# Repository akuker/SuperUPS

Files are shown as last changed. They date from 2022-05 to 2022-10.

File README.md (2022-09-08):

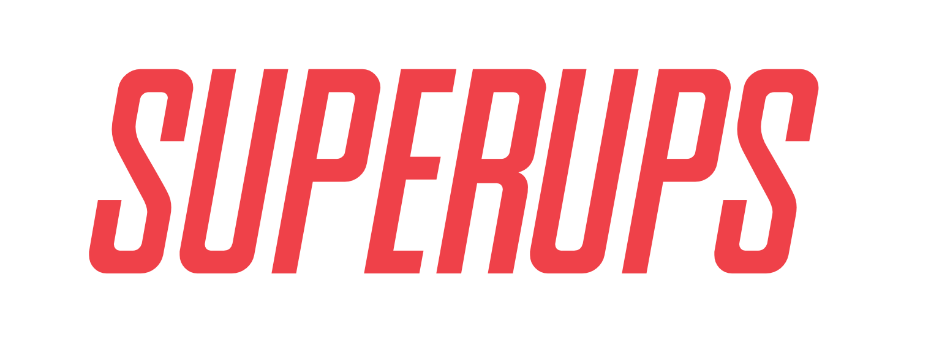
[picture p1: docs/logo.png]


# Supercapacitor UPS board for Raspberry Pi

This is a fork of the original Supercapacitor UPS board for a Raspberry Pi by Scott Baker, http://www.smbaker.com/

This fork is intended to improve producability, documentation and provide tighter integration with the RaSCSI project. This project does NOT require a RaSCSI to function.

See [SETUP.md](SETUP.md) for setup instructions

## Very early 3D renderings

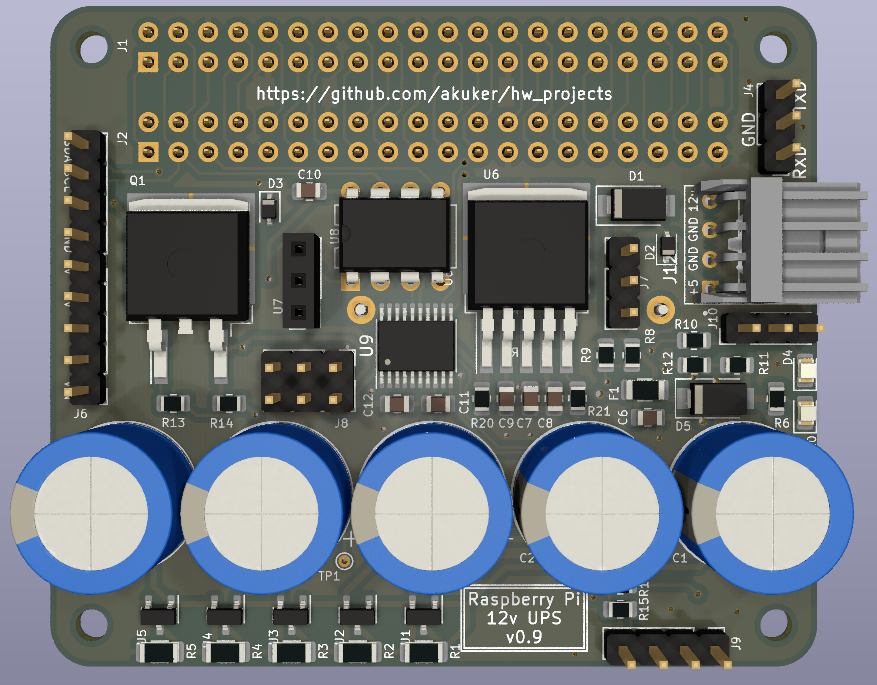
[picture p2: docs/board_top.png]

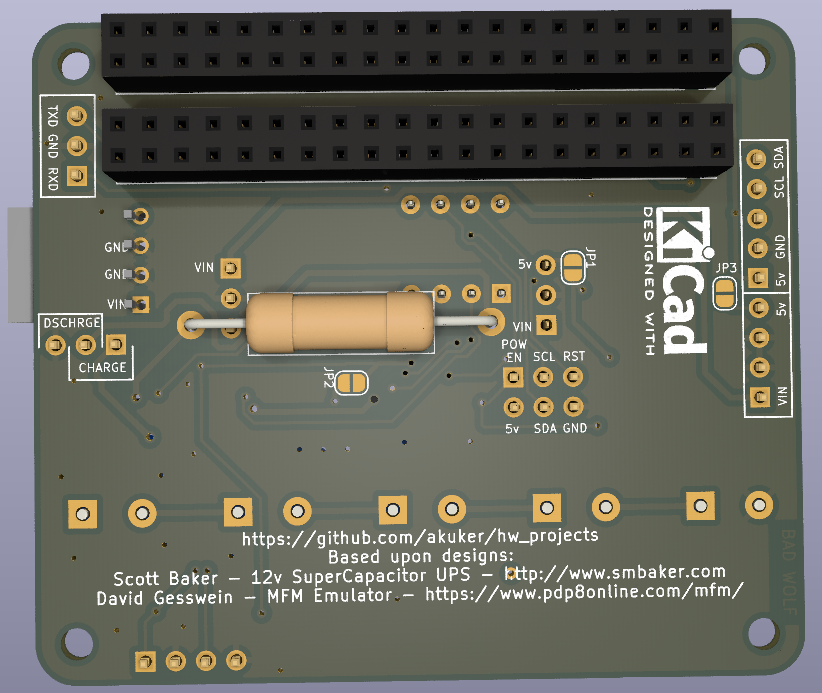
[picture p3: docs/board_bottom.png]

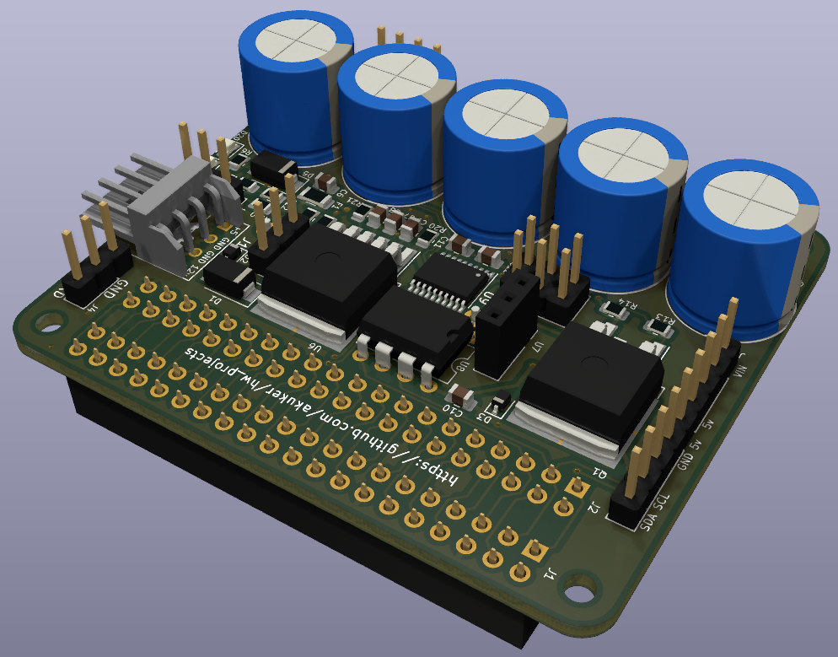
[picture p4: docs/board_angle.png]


## Why not other Supercapacitor designs?

Most of the existing Raspberry Pi UPS designs rely on GPIO pins to alert the Raspberry Pi of a power loss. The RaSCSI design makes heavy usage of the GPIO pins, so there are not sufficient spare to allow this. This design will utilize a microcontroller to manage the power and allow the Rapsberry Pi to read the status through I2C.

# Purpose

These boards are supercapacitor-based uninterruptable power supplies. The supercapacitor charges when power is applied, then when the power supply is terminated, the supercapacitor will operate the device long enough for it to shut down safely.

# Design - 12V board (5v output)

The 12V board uses five 2.7V supercapacitors in series, with 2.7V shunt regulators to ensure that no single capacitor is charged to more than 2.5 volts. A 3W resistor is used to limit the current that charges the capacitors. A jumper is provided to allow the capacitors to be rapid discharged. A mosfet is added to allow the load to be turned on/off.

Note: Scott Baker's original design also included a version of the UPS board that took a 5v input. This fork is focusing on the 12v version and will not include the 5v input version.

# Microcontroller manager

~~An ATTiny85 is used as the controller for the UPS.~~ *Now a STM8 due to the parts shortages.* The microcontroller monitors the battery voltage and the incoming voltage, and switches the load on and off. The microcontroller supports I2C and can be interfaced directly to a raspberry pi.

The microcontroller is also responsible for noticing when power has been restored, and turning the load back on.

[Design Overview](docs/microcontroller_design.md)

# Linux Daemon

A Linux daemon, running on the raspberry pi, monitors the voltage by making i2c queries to the ups board's microcontroller. If the daemon sees the incoming voltage drop, then it will initiate shutdown, by running the `shutdown` command. The shutdown command will terminate processes, unmount the filesystem, etc. 

~~As a final step during shutdown, Linux systemd will execute a script that will tell the microcontroller to turn off the load. At this point, the root filesystem has been remounted readonly, so the board can safely be powered off. ~~

# ~~smb-pi-lib~~

~~Scott Baker has a second repository that has common code for a number of my projects, including the ups. It's located at [https://github.com/sbelectronics/smb-pi-lib](https://github.com/sbelectronics/smb-pi-lib)~~

# Acknowledgements

* Scott Baker for doing a fantastic supercapcitor based UPS design.
* David Gesswein's MFM Emulator was the inspiration for the supercapacitor charing circuit.

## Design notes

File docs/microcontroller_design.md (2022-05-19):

# I2C Register Definitions

| Offset | Description |
| --- | --- |
| 0x00 | Reserved |
| 0x01 | Reserved |
| 0x02 | vin - low (reserved)  |
| 0x03 | vin - high |
| 0x04 | vups - low (reserved) |
| 0x05 | vups - high |
| 0x06 | mosfet switch state |
| 0x07 | on threshold |
| 0x08 | off threshold |
| 0x09 | countdown in 100ms units |
| 0x0A | cycle delay |
| 0x0B | fail-shutdown delay |
| 0x0C | run counter |
| 0x0D | powerup threshold |
| 0x0E | software shutdown threshold |
| 0x0F | R1 resistor value |
| 0x10 | R2 resistor value |
  
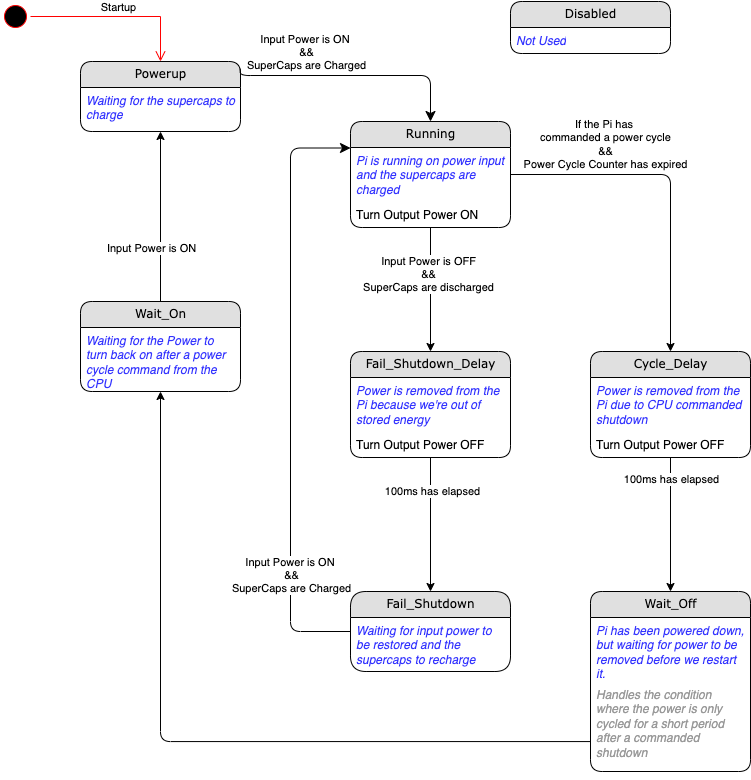
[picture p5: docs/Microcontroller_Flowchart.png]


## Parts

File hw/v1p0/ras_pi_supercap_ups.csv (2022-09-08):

Comment | Designator | Footprint | LCSC
10F | C1,C2,C3,C4,C5 | Capacitor_THT:CP_Radial_D10.0mm_P5.00mm | DNP
1u | C11,C12 | Capacitor_SMD:C_0805_2012Metric | C28323
4.7u | C15,C16 | Capacitor_SMD:C_0805_2012Metric | C1779
4.7n | C17,C20 | Capacitor_SMD:C_0805_2012Metric | C1744
10n | C19 | Capacitor_SMD:C_0805_2012Metric | C1710
33u | C21,C23 | Capacitor_SMD:C_0805_2012Metric | C432920
39p | C22 | Capacitor_SMD:C_0805_2012Metric | C296098
10u | C7,C8,C10,C13 | Capacitor_SMD:C_0805_2012Metric | C15850
100n | C9,C14,C18 | Capacitor_SMD:C_0805_2012Metric | C28233
PTVSHC3D15VUH | D1,D7 | Diode_SMD:D_SOD-323 | C312234
SS54 | D2,D4,D8 | Diode_SMD:D_SMA | C22452
Green | D3,D5,D6,D9 | LED_SMD:LED_0805_2012Metric | C2297
Fuse_Small | F1,F2 | Fuse:Fuse_1206_3216Metric | C140470
MountingHole | H1,H2,H3,H4 | MountingHole:MountingHole_2.7mm_M2.5 | DNP
Conn_01x03 | J1,J3 | Connector_PinHeader_2.54mm:PinHeader_1x03_P2.54mm_Vertical | DNP
Barrel_Jack | J10 | Connector_BarrelJack:BarrelJack_Wuerth_6941xx301002 | C521451
Conn_01x05 | J2 | Connector_PinHeader_2.54mm:PinHeader_1x05_P2.54mm_Vertical | DNP
171826-4 | J5 | TE_171826-4 | DNP
LEDs and Buttons | J6 | Connector_PinHeader_2.54mm:PinHeader_1x04_P2.54mm_Vertical | DNP
STLinkV2 Connector | J7 | Connector_PinHeader_2.54mm:PinHeader_1x04_P2.54mm_Vertical
Raspberry_Pi_2_3 | J8 | Connector_PinSocket_2.54mm:PinSocket_2x20_P2.54mm_Vertical | DNP
Charge Enb | JP1 | Jumper:SolderJumper-2_P1.3mm_Bridged_RoundedPad1.0x1.5mm
6.8uH | L1 | raspberrypi_supercap_ups_lib:Sunltech_SLO0530H | C325965
10 3W | R1,R28 | raspberrypi_supercap_ups_lib:SMT_Resistor_4122 | C306270
2.2k | R10,R11,R13 | Resistor_SMD:R_0805_2012Metric | C17520
0 | R16,R24 | Resistor_SMD:R_0805_2012Metric | C17477
1k | R2,R3,R4,R5,R6 | Resistor_SMD:R_1206_3216Metric | C4410
332k | R21 | Resistor_SMD:R_0805_2012Metric | C17631
68.1k | R22 | Resistor_SMD:R_0805_2012Metric | C17795
49.9k | R23 | Resistor_SMD:R_0805_2012Metric | C17719
10.2k | R25 | Resistor_SMD:R_0805_2012Metric | C17402
1.5k | R26 | Resistor_SMD:R_0805_2012Metric | C4310
200 | R33 | Resistor_SMD:R_0805_2012Metric | C17557
1k | R7,R14,R15,R18,R19,R27 | Resistor_SMD:R_0805_2012Metric | C17513
10k | R8,R9,R12,R20 | Resistor_SMD:R_0805_2012Metric | C17414
Reset | SW1 | SW_TS-1187A-B-A-B | C318884
KA431SMFTF | U1,U2,U3,U4,U5 | Package_TO_SOT_SMD:SOT-23 | C232815
AMS1117-3.3 | U6 | Package_TO_SOT_SMD:SOT-223-3_TabPin2 | C6186
STM8S003F3P | U7 | Package_SO:TSSOP-20_4.4x6.5mm_P0.65mm | C52717
TPS54331DR | U8 | raspberrypi_supercap_ups_lib:SOIC127P599X175-8N | C9865
Logo_Open_Hardware_Small | Z2 | Symbol:CE-Logo_8.5x6mm_SilkScreen
Logo_Open_Hardware_Small | Z4 | Symbol:OSHW-Logo_7.5x8mm_SilkScreen

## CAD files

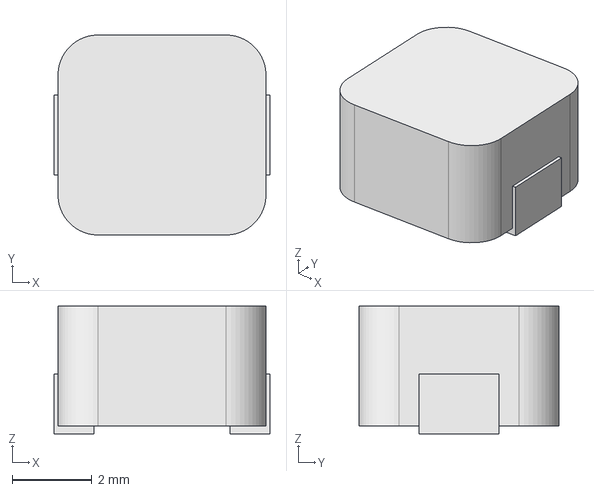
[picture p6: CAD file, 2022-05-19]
hw/v1p0/SLO0530H_Model.FCStd
5.40 x 5.00 x 3.20 mm

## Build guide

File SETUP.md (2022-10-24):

# How to setup SuperUPS

The following assumes you're starting with the base RaSCSI release image from https://github.com/akuker/RaSCSI

## Enable I2C
```
sudo raspi-config
```
Navigate to Interfaces Options -> I2C
When asked if you want I2C to be enabled, select "Yes"

## Install i2c-tools
```
sudo apt install i2c-tools -y
```

## Check if the SuperUPS board is working
```
pi@rascsi:~ $ sudo i2cdetect -y 1
     0  1  2  3  4  5  6  7  8  9  a  b  c  d  e  f
00:                         -- -- -- -- -- -- -- -- 
10: -- -- -- -- -- -- -- -- -- -- -- -- -- -- -- -- 
20: -- -- -- -- -- -- -- -- -- -- -- -- -- -- -- -- 
30: -- -- -- -- -- -- -- -- -- -- -- -- -- -- -- -- 
40: -- -- -- -- -- -- -- -- -- -- -- -- -- -- -- -- 
50: -- -- 52 -- -- -- -- -- -- -- -- -- -- -- -- -- 
60: -- -- -- -- -- -- -- -- -- -- -- -- -- -- -- -- 
70: -- -- -- -- -- -- -- --                         
pi@rascsi:~ $ 
```

The SuperUPS should be at i2c address 0x52

Now, check that you can properly read from it. Registers 16 and 17 are the resistor values of the voltage divider on the board. They should match the example below.
```
pi@rascsi:~ $ i2cget -y 1 0x52 16
0x64
pi@rascsi:~ $ i2cget -y 1 0x52 17
0x16
pi@rascsi:~ $ 
```

## Download the SuperUPS Github repo
```
pi@rascsi:~ $ git clone https://github.com/akuker/SuperUPS.git
```

## Install Python packages
```
sudo pip3 install python-daemon
sudo pip3 install smbus
```

## To manually start the UPS monitor
```
cd ~/SuperUPS/host_monitor/
python3 ./superupsdaemon.py
```

## To dump all of the registers from the UPS controller
```
python3 ups.py
```

## To setup the UPS monitor to run automatically
```
sudo cp SuperUPS/host_monitor/*.py /usr/local/bin/
sudo cp SuperUPS/host_monitor/superups.service /etc/systemd/system/
sudo systemctl daemon-reload
sudo systemctl enable superups.service
sudo systemctl start superups
```

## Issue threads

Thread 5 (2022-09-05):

The wiringpi utility is depreciated in Raspbian 11

stinkerton18, 2022-09-05:
Raspberry Pi Version: 3B
RaSCSI Board: Fullspec, v2.3
SuperUPS Version: 1.0 pre-release

OS Release:
```
console@centris-pi:~ $ lsb_release -a
No LSB modules are available.
Distributor ID: Raspbian
Description:    Raspbian GNU/Linux 11 (bullseye)
Release:        11
Codename:       bullseye
```

Following the install instructions, the first step/prerequisite package install fails on Raspbian 11: Bullseye with the following errors:
```console@centris-pi:~ $ sudo apt-get install -y wiringpi python-smbus python-pip python3-setuptools
Reading package lists... Done
Building dependency tree... Done
Reading state information... Done
Package python-smbus is not available, but is referred to by another package.
This may mean that the package is missing, has been obsoleted, or
is only available from another source

Package python-pip is not available, but is referred to by another package.
This may mean that the package is missing, has been obsoleted, or
is only available from another source
However the following packages replace it:
  python3-pip

Package wiringpi is not available, but is referred to by another package.
This may mean that the package is missing, has been obsoleted, or
is only available from another source

E: Package 'wiringpi' has no installation candidate
E: Package 'python-smbus' has no installation candidate
E: Package 'python-pip' has no installation candidate
```

stinkerton18, 2022-09-05:
In searching, I found this article: https://raspberrypi.stackexchange.com/questions/133251/wiringpi-is-missing-from-bullseye-how-do-i-install-it
According to the article, pigpio is the better option anyways and I see the setup instructions for it in the SETUP doc, This might just be a doc clean up bug.

akuker, 2022-09-07:
Could you take a look at pull request https://github.com/akuker/SuperUPS/pull/8 ? I think this addresses your concern.

The new version shouldn't use wiring pi.

stinkerton18, 2022-09-07:
Can confirm, pull request #8 removed the wiring pi and pigpiod needs

Closed 2022-09-07.

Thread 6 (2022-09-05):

Host Monitoring Script missing dependency libraries

stinkerton18, 2022-09-05:
Raspberry Pi Version: 3B
RaSCSI Board: Fullspec, v2.3
SuperUPS Version: 1.0 pre-release

OS Release:
```
console@centris-pi:~ $ lsb_release -a
No LSB modules are available.
Distributor ID: Raspbian
Description:    Raspbian GNU/Linux 11 (bullseye)
Release:        11
Codename:       bullseye
```

When setting up the host_monitior script, upscontrol.py, it is attempting to import libraries that are missing from this repository but are included in a separate repository from the original/forked project. These missing dependencies are as follows:
- https://github.com/sbelectronics/smb-pi-lib/blob/master/smbpi/ups.py
- https://github.com/sbelectronics/smb-pi-lib/blob/master/smbpi/i2c_with_crc.py

stinkerton18, 2022-09-05:
I've combined these two into a single python script (kept getting errors with the i2c_with_crc module failing to import even with an absolute path added).
This is the contents of ups.py:
```
from __future__ import print_function
import crc8
import time
import traceback

class I2CError(Exception):
    pass

class ReceiveCRCError(Exception):
    pass

class ReceiveSizeError(Exception):
    pass

class ReceiveUninitializedError(Exception):
    pass

class CRCError(Exception):
    pass

class NoMoreRetriesError(Exception):
    pass

class I2CWithCrc:
    def __init__(self, bus=None, addr=0x4, pi=None, sdaPin=2, sclPin=3):
        self.bus = bus
        self.addr = addr
        self.pi = pi
        self.sdaPin = sdaPin
        self.sclPin = sclPin

        self.errorIO = 0
        self.errorCRC = 0
        self.errorReceiveCRC = 0
        self.errorReceiveUninitialized = 0
        self.errorReceiveSize = 0
        self.errorSuccess = 0

        if (self.pi):
            try:
                self.pi.bb_i2c_close(self.sdaPin)
            except:
                pass
            # pigpiod
            self.pi.bb_i2c_open(self.sdaPin, self.sclPin, 100000)

    @property
    def errorCount(self):
        return self.errorIO + self.errorReceiveCRC + self.errorReceiveUninitialized + self.errorReceiveSize + self.errorCRC

    def readreg_once(self, reg):
        if self.bus:
            hash = crc8.crc8()
            hash.update(chr(reg))
            crc = hash.digest()
            self.bus.write_i2c_block_data(self.addr, reg, [ord(crc)])

            data = self.bus.read_byte(self.addr)
            crc = self.bus.read_byte(self.addr)
        else:
            hash = crc8.crc8()
            hash.update(chr(reg))
            crc = hash.digest()
            (count, i2cdata) = self.pi.bb_i2c_zip(self.sdaPin,
                (4, self.addr,      # set addr to self.addr
                2, 7, 2, reg, crc,  # start, write two byte (reg, crc)
                2, 6, 1,            # (re)start, read one byte
                2, 6, 1,            # (re)start, read one byte
                3,                  # stop
                0))                 # end
            if count<0:
                raise I2CError("i2c error")
            if count!=2:
                raise I2CError("i2c wrong byte count")

            data = i2cdata[0]
            crc = i2cdata[1]

        if (data == 0xFF) and (crc == 0xFF):
            raise ReceiveCRCError("receive crc error")
        if (data == 0xFF) and (crc == 0xFE):
            raise ReceiveSizeError("receive size error")
        if (data == 0xFF) and (crc == 0xFD):
            raise ReceiveUninitializedError("receive uninitialized error")

        hash = crc8.crc8()
        hash.update(chr(data))
        if crc != ord(hash.digest()):
            raise CRCError("crc error, data=%2X, crc=%2X, localCrc=%X" % (data, crc, ord(hash.digest())))

        return data

    def writereg_once(self, reg, v):
        if self.bus:
            hash = crc8.crc8()
            hash.update(chr(reg))
            hash.update(chr(v))
            crc = hash.digest()
            self.bus.write_i2c_block_data(self.addr, reg, [v, ord(crc)])

            readBack = self.bus.read_byte(self.addr)
            crc = self.bus.read_byte(self.addr)
        else:
            hash = crc8.crc8()
            hash.update(chr(reg))
            hash.update(chr(v))
            crc = hash.digest()
            (count, i2cdata) = self.pi.bb_i2c_zip(self.sdaPin,
                (4, self.addr,         # set addr to self.addr
                2, 7, 3, reg, v, crc,  # start, write three bytes (reg, v, crc)
                2, 6, 1,            # (re)start, read one byte
                2, 6, 1,            # (re)start, read one byte
                3,                  # stop
                0))                 # end
            if count<0:
                raise I2CError("i2c error")
            if count!=2:
                raise I2CError("i2c wrong byte count")

            readBack = i2cdata[0]
            crc = i2cdata[1]

        # note that readBack will actually return the next register. But,
        # that's alright, we don't care -- we just want to check to make
        # sure we didn't get an error back.

        if (readBack == 0xFF) and (crc == 0xFF):
            raise ReceiveCRCError("receive crc error")
        if (readBack == 0xFF) and (crc == 0xFE):
            raise ReceiveSizeError("receive size error")
        if (readBack == 0xFF) and (crc == 0xFD):
            raise ReceiveUninitializedError("receive uninitialized error")

        hash = crc8.crc8()
        hash.update(chr(readBack))
        if crc != ord(hash.digest()):
            raise CRCError("crc error, readBack=%2X, crc=%2X, localCrc=%X" % (readBack, crc, ord(hash.digest())))

    def readreg(self, reg):
        for i in range(0, 10):
            try:
                v = self.readreg_once(reg)
                self.errorSuccess += 1
                return v
            except I2CError:
                self.errorIO += 1
            except IOError:
                self.errorIO += 1
            except ReceiveCRCError:
                self.errorReceiveCRC += 1
            except ReceiveSizeError:
                self.errorReceiveSize += 1
            except ReceiveUninitializedError:
                self.errorReceivedUninitialized += 1
            except CRCError:
                self.errorCRC += 1
        raise NoMoreRetriesError()

    def writereg(self, reg, v):
        for i in range(0, 10):
            try:
                self.writereg_once(reg, v)
                self.errorSuccess += 1
                return
            except I2CError:
                self.errorIO += 1
            except IOError:
                self.errorIO += 1
            except ReceiveCRCError:
                self.errorReceiveCRC += 1
            except ReceiveSizeError:
                self.errorReceiveSize += 1
            except ReceiveUninitializedError:
                self.errorReceivedUninitialized += 1
            except CRCError:
                self.errorCRC += 1
            except TypeError:
                pass
        raise NoMoreRetriesError()

    # different capitalization
    def readReg(self, reg):
        return self.readreg(reg)

    # different capitalization
    def writeReg(self, reg, v):
        self.writereg(reg, v)

class UPS(I2CWithCrc):
    def __init__(self, bus=None, addr=0x4, pi=None, sdaPin=2, sclPin=3):
        I2CWithCrc.__init__(self, bus, addr, pi, sdaPin, sclPin)

        try:
            self.r1 = self.readR1()
            self.r2 = self.readR2()
            print("XXX", self.r1, self.r2)
        except:
            print("WARNING: Failed to read R1 and R2")
            traceback.print_exc()

        self.states = {0: "DISABLED",
                       1: "WAIT_OFF",
                       2: "WAIT_ON",
                       3: "POWERUP",
                       4: "RUNNING",
                       5: "FAIL_SHUTDOWN",
                       6: "FAIL_SHUTDOWN_DELAY",
                       7: "CYCLE_DELAY"}

    def vConv(self, x):
        return float(x)*2.56*(self.r1+self.r2)/self.r2/256.0

    def setCountdown(self, ms):
        if (ms is not None) and (ms>0) and (ms<100):
            # the minimum is 100ms
            ms=100
        return self.writereg(9, ms/100)

    def readR1(self):
        return self.readreg(16)

    def readR2(self):
        return self.readreg(17)

    def readCountdown(self):
        return self.readreg(9)

    def readVIN(self):
        return self.vConv(self.readreg(3))

    def readVUPS(self):
        return self.vConv(self.readreg(5))

    def readOnThresh(self):
        return self.vConv(self.readreg(7))

    def readOffThresh(self):
        return self.vConv(self.readreg(8))

    def readPowerUpThresh(self):
        return self.vConv(self.readreg(14))

    def readShutdownThresh(self):
        return self.vConv(self.readreg(15))

    def readMosfet(self):
        return self.readreg(6)

    def setMosfet(self, v):
        self.writeReg(6, v)

    def readState(self):
        return self.readreg(10)

    def readRunCounter(self):
        return self.readreg(13)

    def readStateStr(self):
        state = self.readState()
        return self.states.get(state, str(state))

    def testWrite(self, x):
        self.writereg(0, x)

def diags(ups):
    print(ups.readreg(0), ups.readreg(2), ups.readreg(4), ups.readreg(6), ups.readreg(7), ups.readreg(8))
    print("onThresh=%0.2f, offThresh=%0.2f" % (ups.readOnThresh(), ups.readOffThresh()))

    lastVUPS = None
    lastVIN = None
    lastState = None
    lastCountdown = None
    lastErrorCount = 0
    count = 0
    while True:
        try:
            VUPS = ups.readVUPS()
            VIN = ups.readVIN()
            state = ups.readStateStr()
            runCounter = ups.readRunCounter()
            countdown = ups.readCountdown()
        except NoMoreRetriesError:
            continue

        try:
            ups.testWrite(count % 256)
        except NoMoreRetriesError:
            pass

        if (VUPS != lastVUPS) or (VIN != lastVIN) or (state != lastState) or (countdown != lastCountdown):
            print("%-20s, vin=%0.2f, vups=%0.2f rc=%d cd=%d" % (state, VIN, VUPS, runCounter, countdown))
            lastVUPS = VUPS
            lastVIN = VIN
            state = lastState

        errorCount = ups.errorCount
        if errorCount != lastErrorCount:
            print("ERR: success=%d, io=%d, crc=%d, rcv_crc=%d, rcv_size=%d, rcv_uninit=%d" % (ups.errorSuccess, ups.errorIO, ups.errorCRC, ups.errorReceiveCRC, ups.errorReceiveSize, ups.errorReceiveUninitialized))
            lastErrorCount = errorCount

        time.sleep(0.01)

def main():
    #import smbus
    #bus = smbus.SMBus(1)
    #ups = UPS(bus=bus)

    import pigpio
    pi = pigpio.pi()
    ups = UPS(pi=pi)

    diags(ups)

if __name__ == "__main__":
    main()
```

Then line 11 of upscontrol.py should be changed to:
`from ups import UPS, diags`

_if_ the ups.py script is placed in the same directory as the upscontrol.py script of course.

akuker, 2022-09-07:
Could you take a look at pull request https://github.com/akuker/SuperUPS/pull/8 ? I think this addresses your concern.

Note: I've SUBSTANTIALLY simplified the python script from Dr. Baker's original version. There was a lot of functionality that I don't think is needed right away.

stinkerton18, 2022-09-07:
100% can confirm with pull request #8.

Closed 2022-09-07.

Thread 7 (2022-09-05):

upscontrol.py script is not Python3 compliant

stinkerton18, 2022-09-05:
Raspberry Pi Version: 3B
RaSCSI Board: Fullspec, v2.3
SuperUPS Version: 1.0 pre-release

OS Release:
```
console@centris-pi:~ $ lsb_release -a
No LSB modules are available.
Distributor ID: Raspbian
Description:    Raspbian GNU/Linux 11 (bullseye)
Release:        11
Codename:       bullseye
```

The upscontrol.py script is using the older Python2-based print statements. I have corrected this for Python3 and can create a merge request with the updated (or renamed for python3) upscontrol.py script.

akuker, 2022-09-07:
I've made significant updates to the python code that is on a branch. I haven't merged it to main yet :-(

https://github.com/akuker/SuperUPS/blob/host_controller/host_monitor/upscontrol.py

akuker, 2022-09-07:
Could you take a look at pull request #8 ? I think this addresses your concern.

stinkerton18, 2022-09-07:
Yes indeed. Since there's a different script, I don't see a reason to publish the minor changes to make it python3 compliant in this repo.

Closed 2022-09-07.

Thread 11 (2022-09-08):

Version 1.0 hardware is missing pull-up resistors for the I2C bus

akuker, 2022-09-08:
The board should be modified to add pull-up resistors for the i2c bus. Current 1.0 boards have modifications to work around this.

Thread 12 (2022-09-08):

Re-do board layout to fit within the Raspberry Pi footprint

akuker, 2022-09-08:
Right now, the super caps extend beyond the footprint of the raspberry pi. Ideally, they should be within that footprint.

Some space saving ideas:
- Several of the headers can be removed, as they were only for debugging
- The reset switch could be moved to the bottom and depopulated for most board. This is only used for firmware development (if even then)
- The voltage sensing resistors could be dropped down to 0402, since they have almost no current flowing through them.

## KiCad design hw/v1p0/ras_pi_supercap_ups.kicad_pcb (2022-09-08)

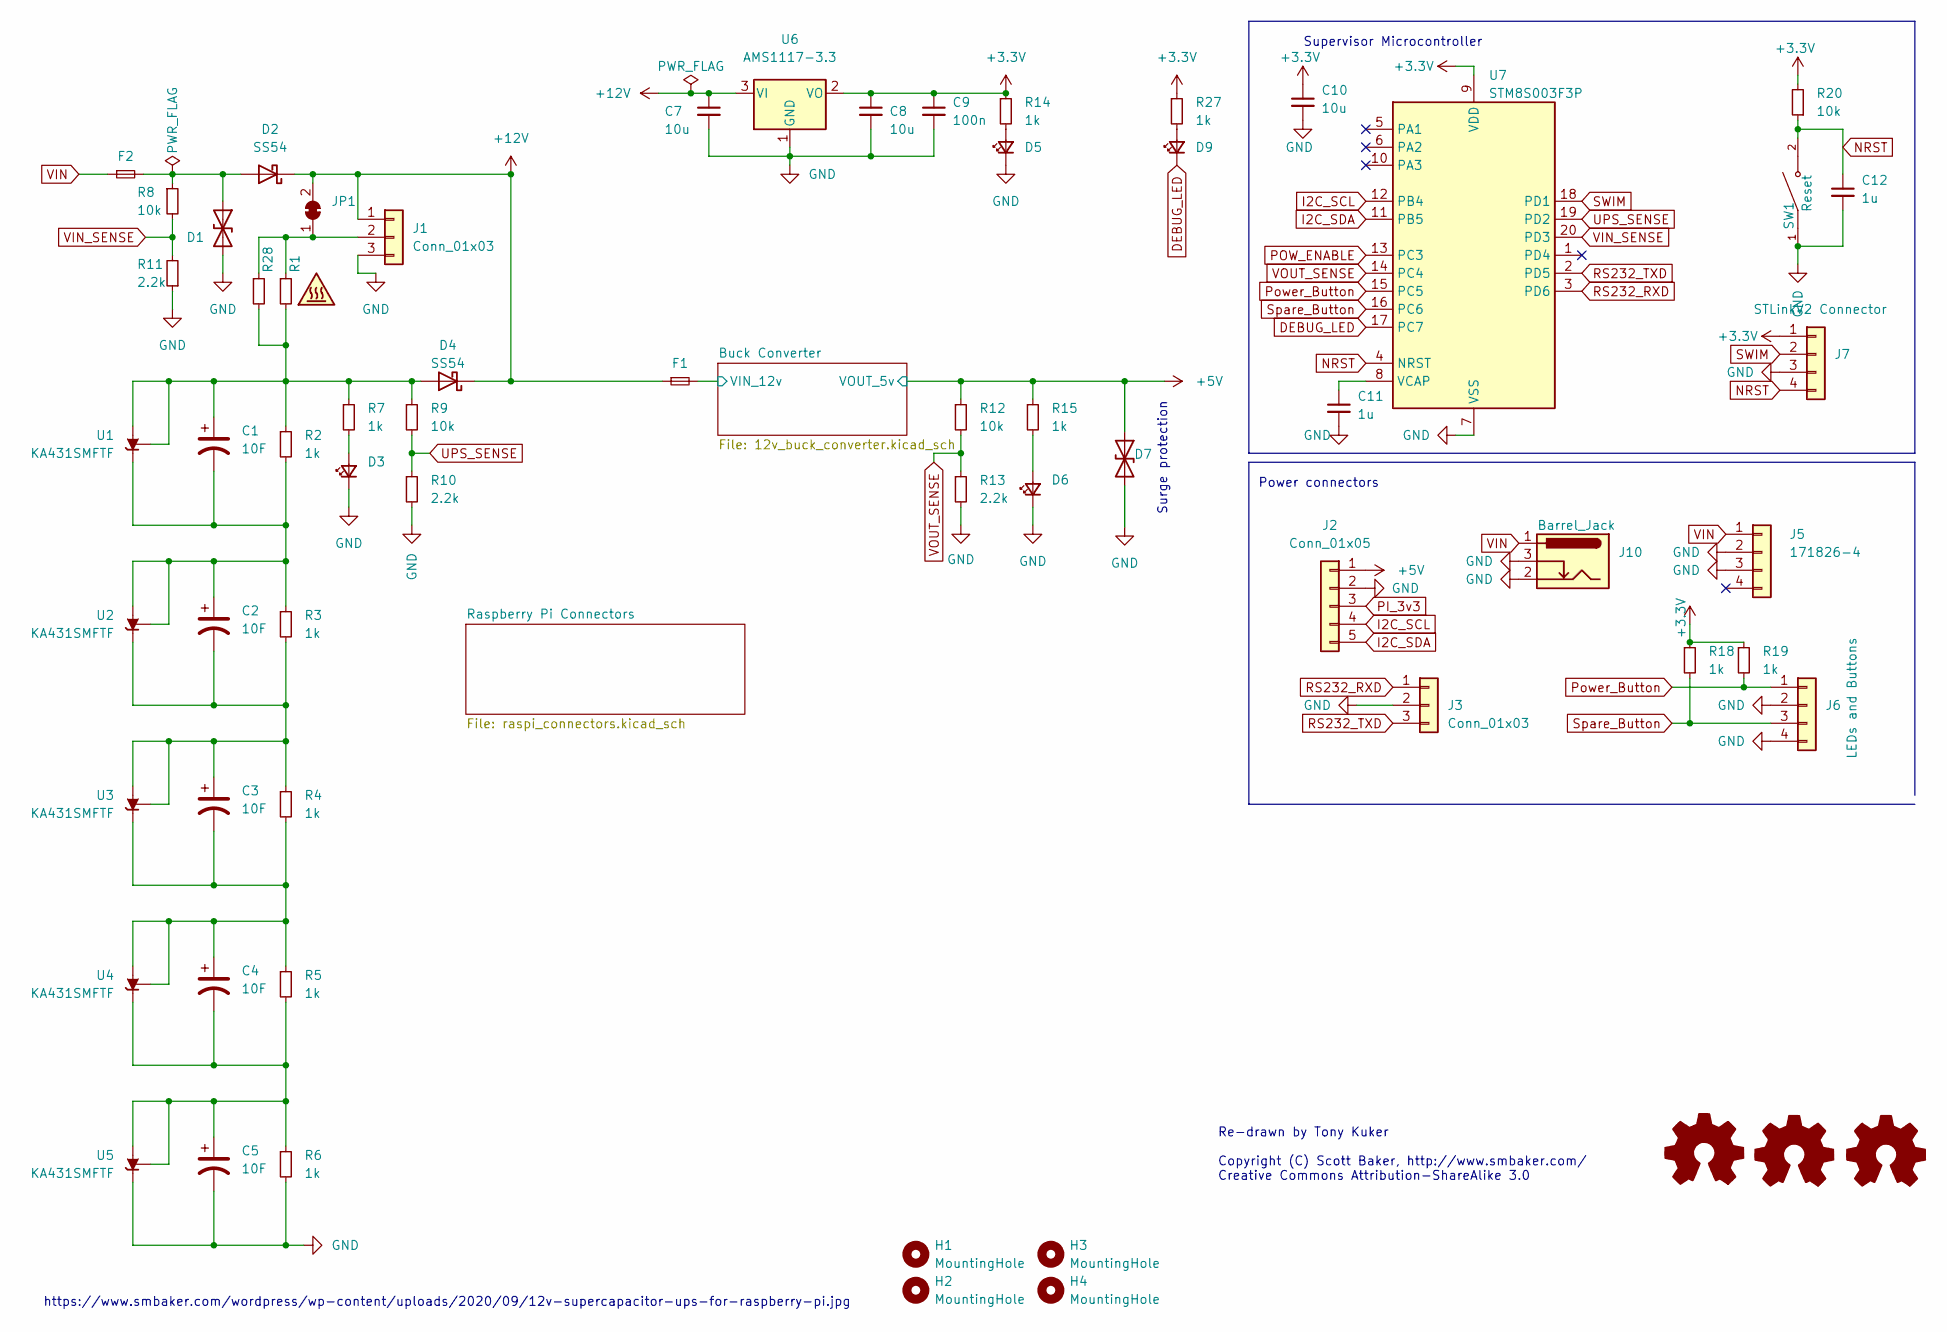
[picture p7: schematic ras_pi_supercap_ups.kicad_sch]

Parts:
C1, C2, C3, C4, C5: 10F; CP_Radial_D10.0mm_P5.00mm; DigikeyPN 478-10996-ND
C7, C8, C10: 10u; C_0805_2012Metric; DigikeyPN 445-FK26X7R1E106K-ND
C9: 100n; C_0805_2012Metric; LCSC C28233
C11, C12: 1u; C_0805_2012Metric; LCSC C28323
D1, D7: PTVSHC3D15VUH; D_SOD-323; LCSC C312234
D2, D4: SS54; D_SMA; LCSC C22452
D3, D5, D6, D9: Green; LED_0805_2012Metric; LCSC C2297
F1, F2: Fuse_Small; Fuse_1206_3216Metric; LCSC C140470
H1, H2, H3, H4: MountingHole; MountingHole_2.7mm_M2.5; LCSC DNP
J1: Conn_01x03; PinHeader_1x03_P2.54mm_Vertical; DigikeyPN NA
J2: Conn_01x05; PinHeader_1x05_P2.54mm_Vertical; DigikeyPN NA
J3: Conn_01x03; PinHeader_1x03_P2.54mm_Vertical; DigikeyPN A106204-ND
J5: 171826-4; TE_171826-4; LCSC DNP
J6: LEDs and Buttons; PinHeader_1x04_P2.54mm_Vertical; LCSC DNP
J7: STLinkV2 Connector; PinHeader_1x04_P2.54mm_Vertical
J10: Barrel_Jack; BarrelJack_Wuerth_6941xx301002; LCSC C521451
JP1: Charge Enb; SolderJumper-2_P1.3mm_Bridged_RoundedPad1.0x1.5mm
R1, R28: 10 3W; SMT_Resistor_4122; DigikeyPN YAG1228CT-ND
R2, R3, R4, R5, R6: 1k; R_1206_3216Metric; DigikeyPN CF14JT1K00CT-ND
R7, R14, R15, R18, R19, R27: 1k; R_0805_2012Metric; DigikeyPN CF14JT1K00CT-ND
R8, R9, R12, R20: 10k; R_0805_2012Metric; DigikeyPN CF14JT10K0CT-ND
R10, R11, R13: 2.2k; R_0805_2012Metric; DigikeyPN CF14JT2K20TR-ND
SW1: Reset; SW_TS-1187A-B-A-B; PARTREV A0; LCSC C318884
U1, U2, U3, U4, U5: KA431SMFTF; SOT-23; LCSC C232815
U6: AMS1117-3.3; SOT-223-3_TabPin2; LCSC C6186
U7: STM8S003F3P; TSSOP-20_4.4x6.5mm_P0.65mm; LCSC C52717
Z1: SYM_Hot_Small; hot_warning_4
Z2: Logo_Open_Hardware_Small; CE-Logo_8.5x6mm_SilkScreen
Z3: Logo_Open_Hardware_Small; KiCad-Logo_5mm_Copper
Z4: Logo_Open_Hardware_Small; OSHW-Logo_7.5x8mm_SilkScreen

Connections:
+3V3: C8.1, C9.1, C10.1, J7.1, R14.1, R18.1, R19.1, R20.2, R27.1, U6.2 (VO), U7.9 (VDD)
+5V: D7.1 (A1), J2.1, R12.1, R15.1; also elsewhere on the board
+12V: C7.1, D2.1 (K), D4.1 (K), F1.1, J1.1, JP1.2 (B), U6.3 (VI)
/Buck Converter/VIN_12v: F1.2; also elsewhere on the board
DEBUG_LED: D9.1 (K), U7.17 (PC7)
GND: C5.2, C7.2, C8.2, C9.2, C10.2, C11.2, C12.2, D1.2 (A2), D3.1 (K), D5.1 (K), D6.1 (K), D7.2 (A2), J1.3, J2.2, J3.2, J5.2, J5.3, J6.2, J6.4, J7.3, J10.2, J10.3, R6.2, R10.2, R11.1, R13.2, SW1.1, U5.2 (K), U6.1 (GND), U7.7 (VSS); also elsewhere on the board
NRST: C12.1, J7.4, R20.1, SW1.2, U7.4 (NRST)
unnamed: C1.1, D4.2 (A), R1.2, R2.1, R7.1, R9.1, R28.2, U1.1 (REF), U1.3 (A)
unnamed: C1.2, C2.1, R2.2, R3.1, U1.2 (K), U2.1 (REF), U2.3 (A)
unnamed: C2.2, C3.1, R3.2, R4.1, U2.2 (K), U3.1 (REF), U3.3 (A)
unnamed: C3.2, C4.1, R4.2, R5.1, U3.2 (K), U4.1 (REF), U4.3 (A)
unnamed: C4.2, C5.1, R5.2, R6.1, U4.2 (K), U5.1 (REF), U5.3 (A)
unnamed: C11.1, U7.8 (VCAP)
unnamed: D1.1 (A1), D2.2 (A), F2.2, R8.1
unnamed: D3.2 (A), R7.2
unnamed: D5.2 (A), R14.2
unnamed: D6.2 (A), R15.2
unnamed: D9.2 (A), R27.2
unnamed: J1.2, JP1.1 (A), R1.1, R28.1
PI_3v3: J2.3; also elsewhere on the board
POW_ENABLE: U7.13 (PC3); also elsewhere on the board
Power_Button: J6.1, R19.2, U7.15 (PC5)
RS232_RXD: J3.1, U7.3 (PD6)
RS232_TXD: J3.3, U7.2 (PD5)
SWIM: J7.2, U7.18 (PD1)
Spare_Button: J6.3, R18.2, U7.16 (PC6)
UPS_SENSE: R9.2, R10.1, U7.19 (PD2)
VIN: F2.1, J5.1, J10.1
VIN_SENSE: R8.2, R11.2, U7.20 (PD3)
VOUT_SENSE: R12.2, R13.1, U7.14 (PC4)

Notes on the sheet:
https://www.smbaker.com/wordpress/wp-content/uploads/2020/09/12v-supercapacitor-ups-for-raspberry-pi.jpg
Power connectors
Re-drawn by Tony Kuker Copyright (C) Scott Baker, http://www.smbaker.com/ Creative Commons Attribution-ShareAlike 3.0
Surge protection
Supervisor Microcontroller

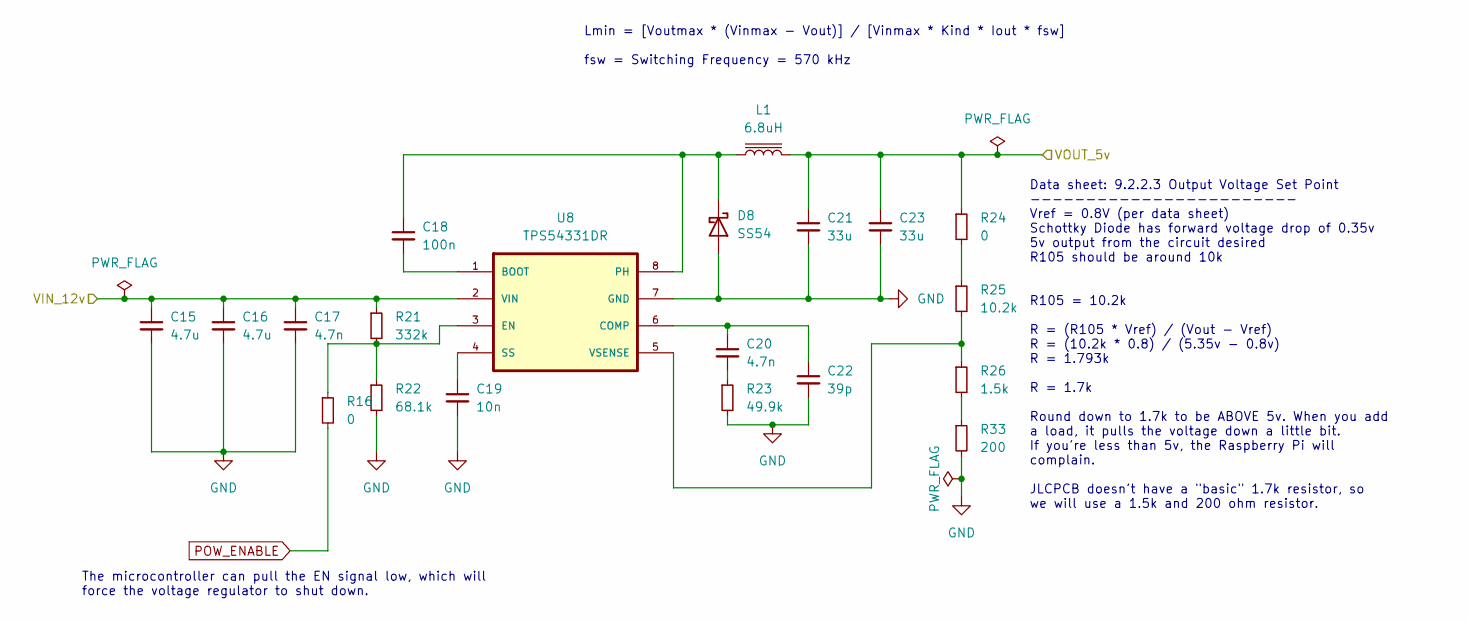
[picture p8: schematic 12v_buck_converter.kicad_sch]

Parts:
C15, C16: 4.7u; C_0805_2012Metric; LCSC C1779
C17, C20: 4.7n; C_0805_2012Metric; LCSC C1744
C18: 100n; C_0805_2012Metric; LCSC C28233
C19: 10n; C_0805_2012Metric; LCSC C1710
C21, C23: 33u; C_0805_2012Metric; LCSC C432920
C22: 39p; C_0805_2012Metric; LCSC C296098
D8: SS54; D_SMA; LCSC C22452
L1: 6.8uH; Sunltech_SLO0530H; LCSC C325965
R16: 0; R_0805_2012Metric; DigikeyPN CF14JT1K00CT-ND
R21: 332k; R_0805_2012Metric; LCSC C17631
R22: 68.1k; R_0805_2012Metric; LCSC C17795
R23: 49.9k; R_0805_2012Metric; LCSC C17719
R24: 0; R_0805_2012Metric; LCSC C17477
R25: 10.2k; R_0805_2012Metric; LCSC C17402
R26: 1.5k; R_0805_2012Metric; LCSC C4310
R33: 200; R_0805_2012Metric; LCSC C17557
U8: TPS54331DR; SOIC127P599X175-8N; LCSC C9865

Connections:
+5V: C21.1, C23.1, L1.2, R24.1; also elsewhere on the board
/Buck Converter/VIN_12v: C15.1, C16.1, C17.1, R21.1, U8.2 (VIN); also elsewhere on the board
GND: C15.2, C16.2, C17.2, C19.2, C21.2, C22.2, C23.2, D8.2 (A), R22.2, R23.2, R33.2, U8.7 (GND); also elsewhere on the board
unnamed: C18.1, D8.1 (K), L1.1, U8.8 (PH)
unnamed: C18.2, U8.1 (BOOT)
unnamed: C19.1, U8.4 (SS)
unnamed: C20.1, C22.1, U8.6 (COMP)
unnamed: C20.2, R23.1
unnamed: R16.1, R21.2, R22.1, U8.3 (EN)
unnamed: R24.2, R25.1
unnamed: R25.2, R26.1, U8.5 (VSENSE)
unnamed: R26.2, R33.1
POW_ENABLE: R16.2; also elsewhere on the board

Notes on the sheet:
The microcontroller can pull the EN signal low, which will force the voltage regulator to shut down.
Data sheet: 9.2.2.3 Output Voltage Set Point ------------------------ Vref = 0.8V (per data sheet) Schottky Diode has forward voltage drop of 0.35v 5v output from the circuit desired R105 should be around 10k R105 = 10.2k R = (R105 * Vref) / (Vout - Vref) R = (10.2k * 0.8) / (5.35v - 0.8v) R = 1.79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
Lmin = [Voutmax * (Vinmax - Vout)] / [Vinmax * Kind * Iout * fsw] fsw = Switching Frequency = 570 kHz

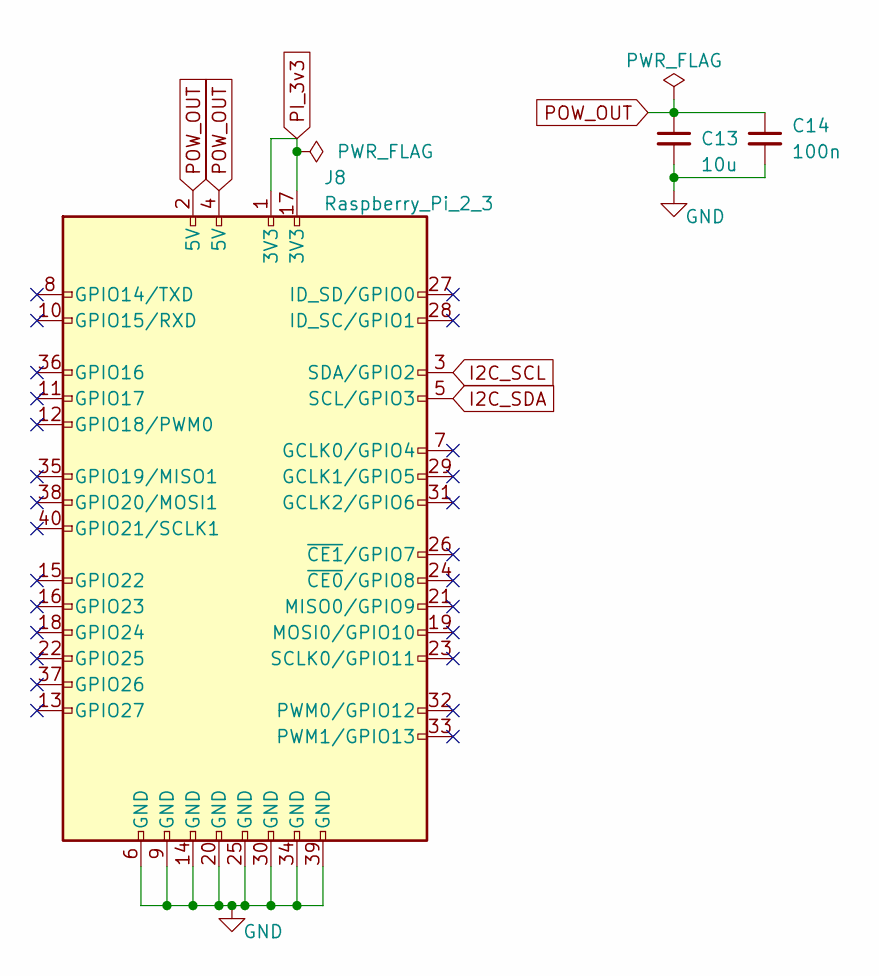
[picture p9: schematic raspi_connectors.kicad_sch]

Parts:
C13: 10u; C_0805_2012Metric; DigikeyPN 445-FK26X7R1E106K-ND
C14: 100n; C_0805_2012Metric; LCSC C28233
J8: Raspberry_Pi_2_3; PinSocket_2x20_P2.54mm_Vertical; LCSC DNP

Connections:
+5V: C13.1, C14.1, J8.2 (5V), J8.4 (5V); also elsewhere on the board
GND: C13.2, C14.2, J8.6 (GND), J8.9 (GND), J8.14 (GND), J8.20 (GND), J8.25 (GND), J8.30 (GND), J8.34 (GND), J8.39 (GND); also elsewhere on the board
PI_3v3: J8.1 (3V3), J8.17 (3V3); also elsewhere on the board

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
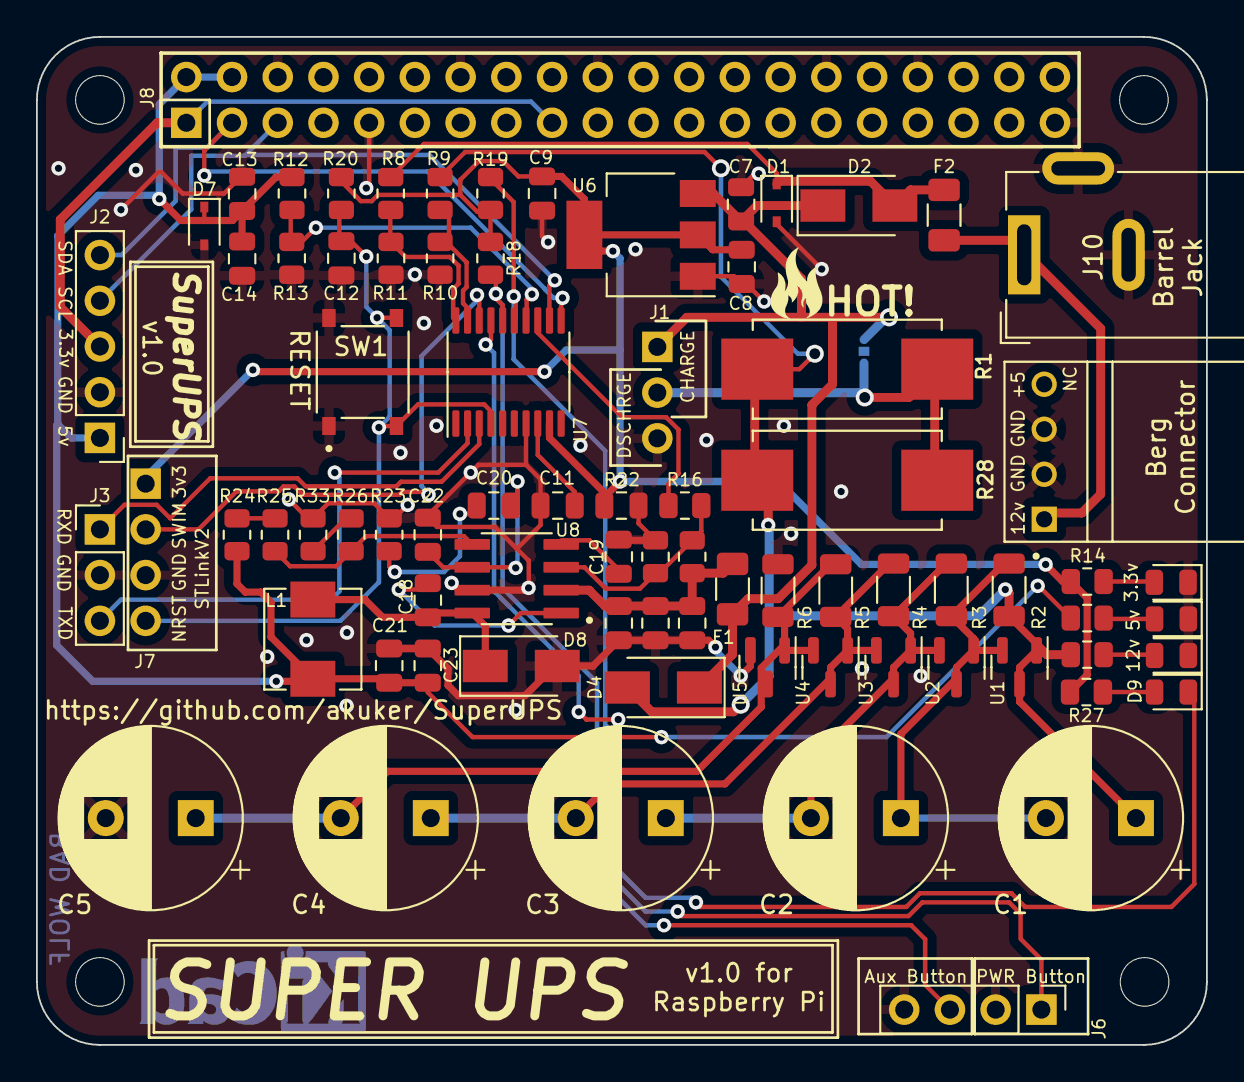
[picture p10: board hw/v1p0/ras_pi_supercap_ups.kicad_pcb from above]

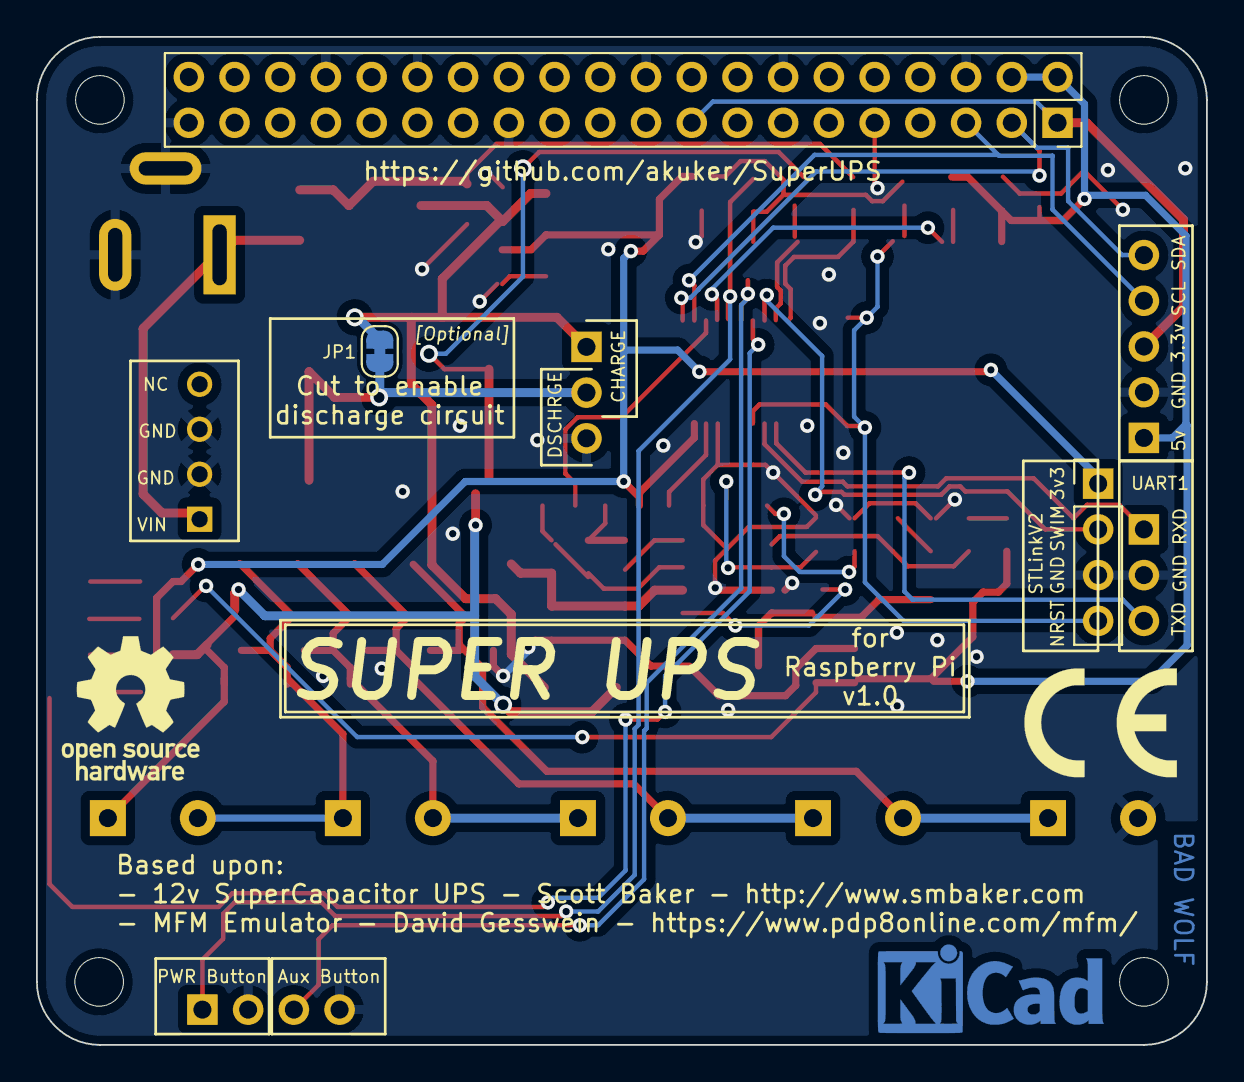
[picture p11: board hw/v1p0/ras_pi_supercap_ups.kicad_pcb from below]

Board: 2 copper layers, 65.0 x 56.0 mm, 88 parts (7 on the bottom side), 41 nets.

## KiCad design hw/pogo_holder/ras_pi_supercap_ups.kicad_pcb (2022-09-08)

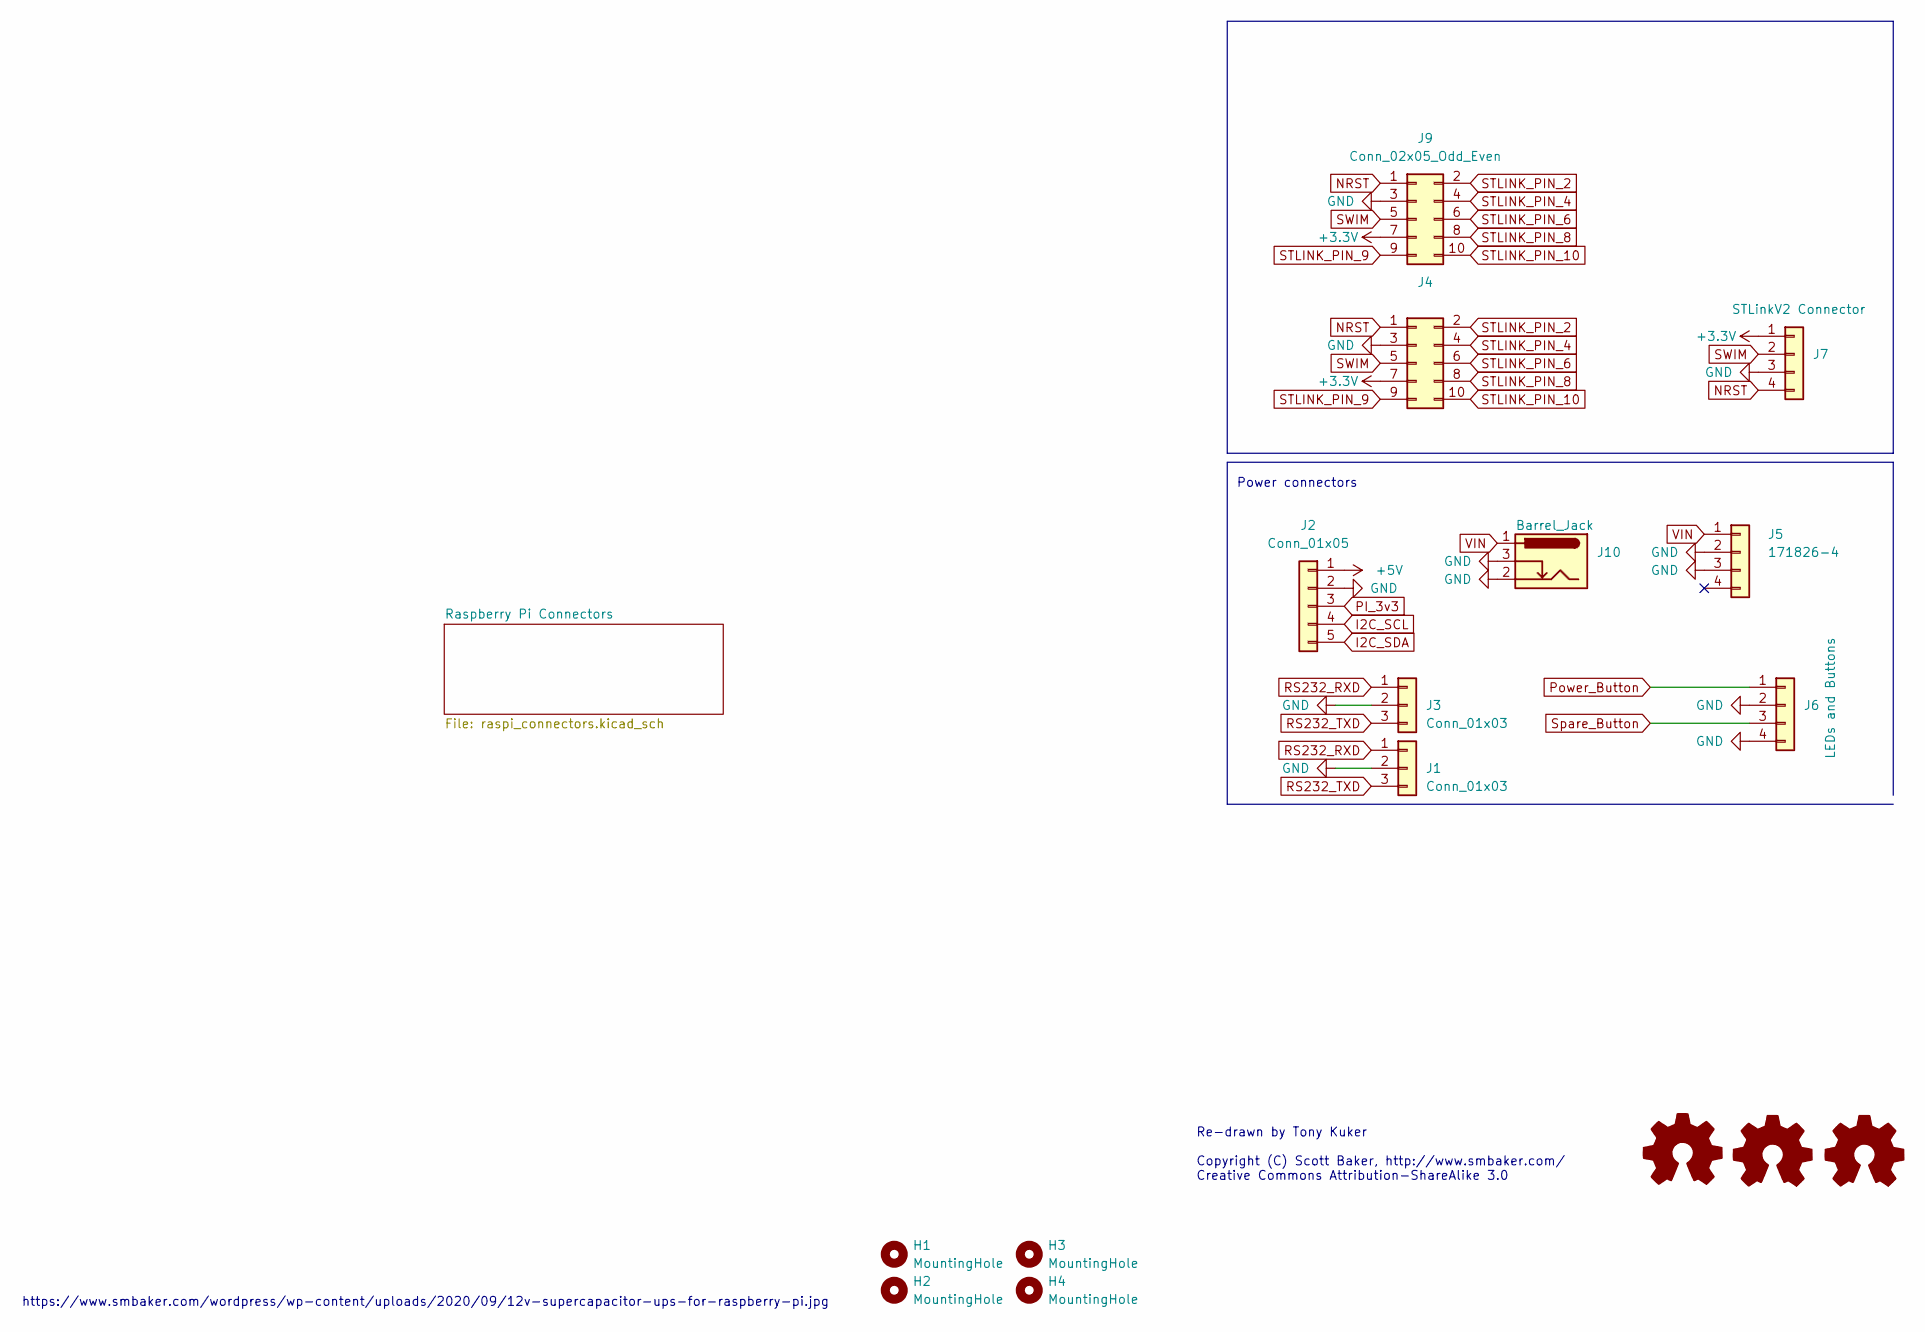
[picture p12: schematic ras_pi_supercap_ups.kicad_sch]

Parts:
H1, H2, H3, H4: MountingHole; MountingHole_2.7mm_M2.5; LCSC DNP
J1, J3: Conn_01x03; PinHeader_1x03_P2.54mm_Vertical; DigikeyPN A106204-ND
J2: Conn_01x05; PinHeader_1x05_P2.54mm_Vertical; DigikeyPN NA
J4: (no value)
J5: 171826-4; TE_171826-4; LCSC DNP
J6: LEDs and Buttons; PinHeader_1x04_P2.54mm_Vertical; LCSC DNP
J7: STLinkV2 Connector; PinHeader_1x04_P2.54mm_Vertical
J9: Conn_02x05_Odd_Even; PinHeader_2x05_P2.54mm_Vertical
J10: Barrel_Jack; BarrelJack_Wuerth_6941xx301002; LCSC C521451
Z2: Logo_Open_Hardware_Small; CE-Logo_8.5x6mm_SilkScreen
Z3: Logo_Open_Hardware_Small; KiCad-Logo_5mm_Copper
Z4: Logo_Open_Hardware_Small; OSHW-Logo_7.5x8mm_SilkScreen

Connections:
+3V3: J4.7, J7.1, J9.7
+5V: J2.1
GND: J1.2, J2.2, J3.2, J4.3, J5.2, J5.3, J6.2, J6.4, J7.3, J9.3, J10.2, J10.3; also elsewhere on the board
I2C_SCL: J2.4; also elsewhere on the board
I2C_SDA: J2.5; also elsewhere on the board
NRST: J4.1, J7.4, J9.1
PI_3v3: J2.3
Power_Button: J6.1
RS232_RXD: J1.1, J3.1
RS232_TXD: J1.3, J3.3
STLINK_PIN_2: J4.2, J9.2
STLINK_PIN_4: J4.4, J9.4
STLINK_PIN_6: J4.6, J9.6
STLINK_PIN_8: J4.8, J9.8
STLINK_PIN_9: J4.9, J9.9
STLINK_PIN_10: J4.10, J9.10
SWIM: J4.5, J7.2, J9.5
Spare_Button: J6.3
VIN: J5.1, J10.1

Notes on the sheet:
https://www.smbaker.com/wordpress/wp-content/uploads/2020/09/12v-supercapacitor-ups-for-raspberry-pi.jpg
Power connectors
Re-drawn by Tony Kuker Copyright (C) Scott Baker, http://www.smbaker.com/ Creative Commons Attribution-ShareAlike 3.0

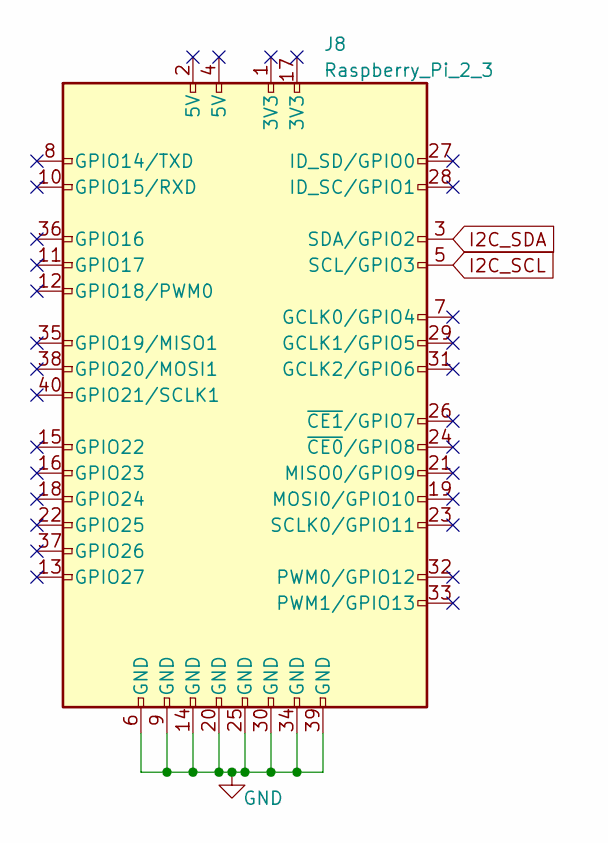
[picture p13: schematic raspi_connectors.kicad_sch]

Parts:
J8: Raspberry_Pi_2_3; PinSocket_2x20_P2.54mm_Vertical; LCSC DNP

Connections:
GND: J8.6 (GND), J8.9 (GND), J8.14 (GND), J8.20 (GND), J8.25 (GND), J8.30 (GND), J8.34 (GND), J8.39 (GND); also elsewhere on the board
I2C_SCL: J8.5 (SCL/GPIO3); also elsewhere on the board
I2C_SDA: J8.3 (SDA/GPIO2); also elsewhere on the board

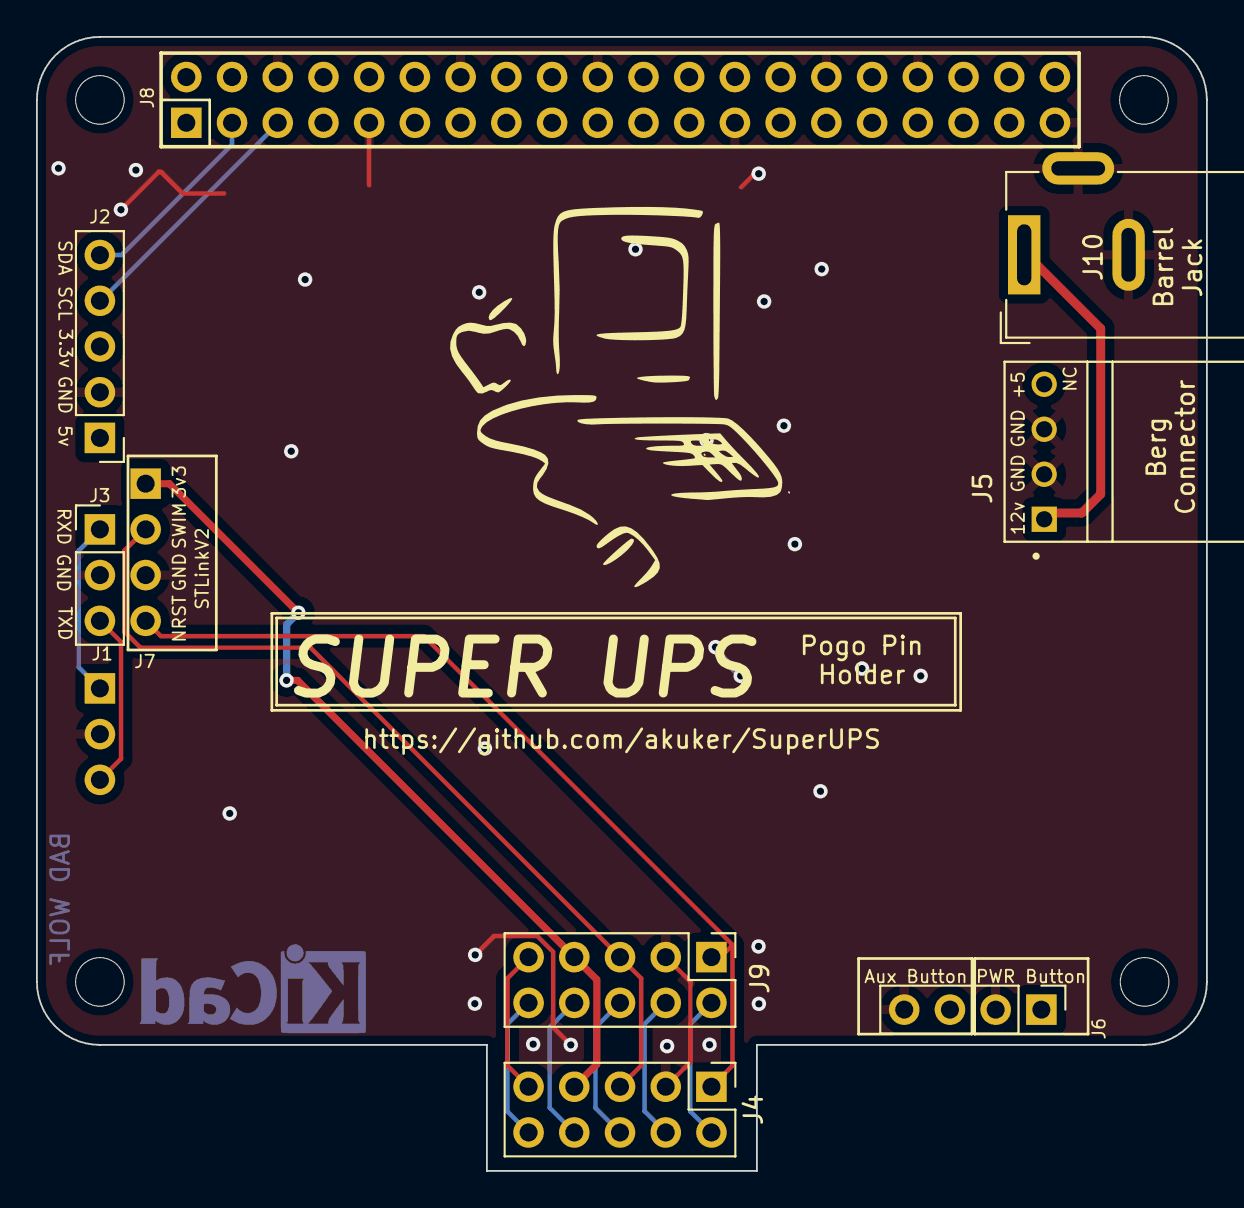
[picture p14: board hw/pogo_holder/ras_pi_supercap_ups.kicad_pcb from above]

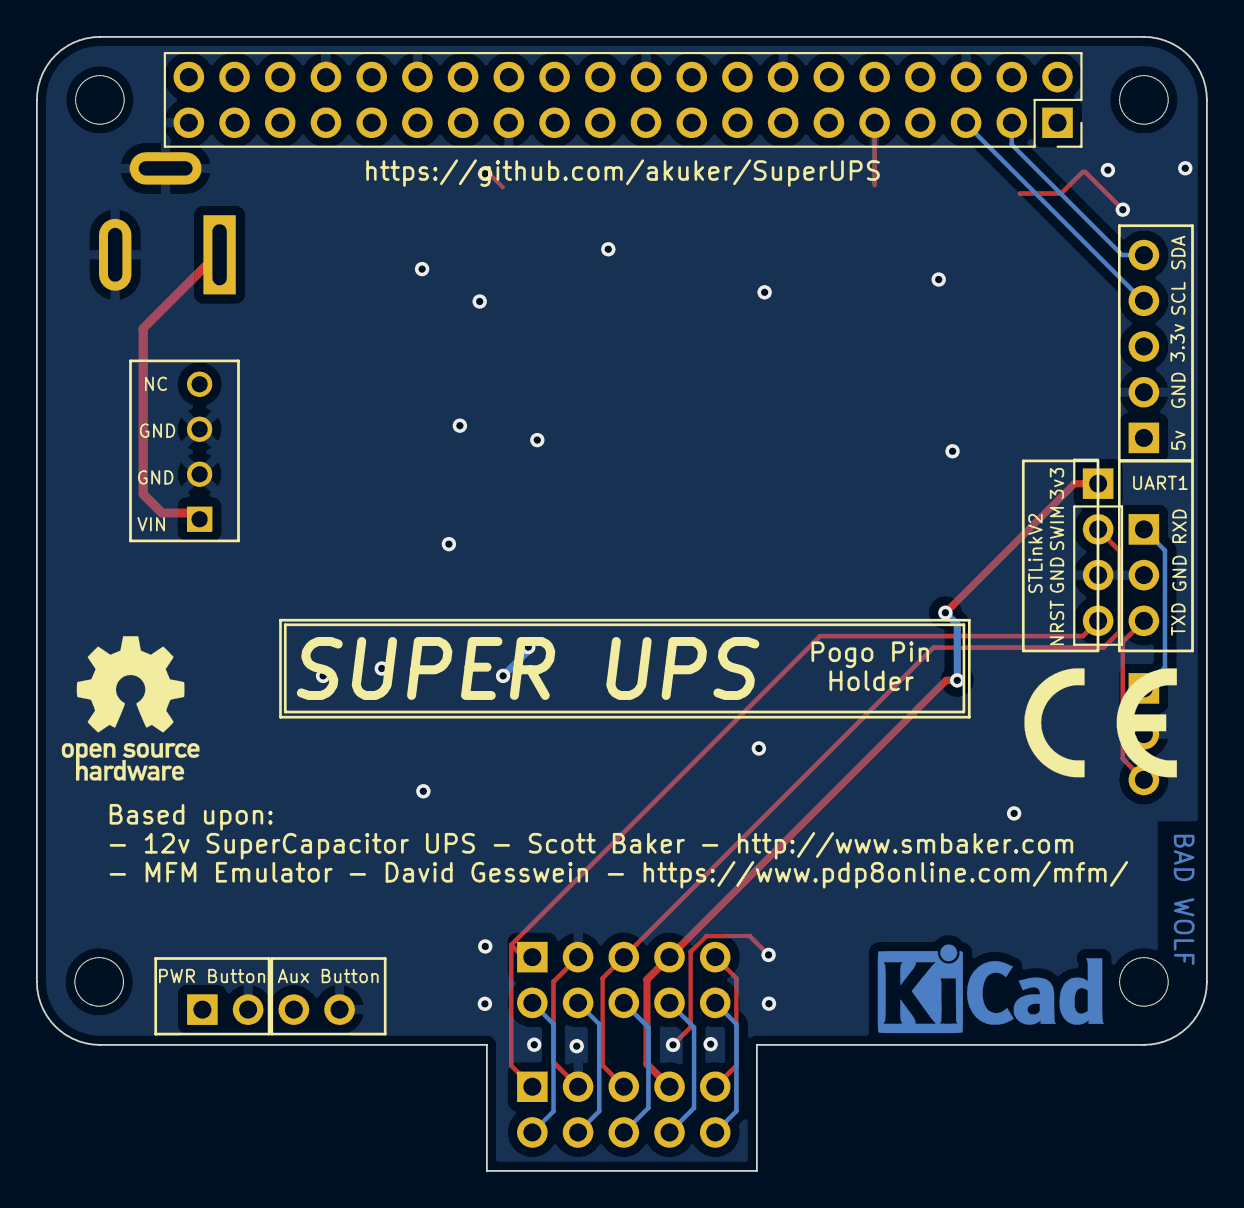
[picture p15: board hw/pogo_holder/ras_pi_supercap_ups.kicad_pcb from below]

Board: 2 copper layers, 65.0 x 63.0 mm, 17 parts (6 on the bottom side), 15 nets.

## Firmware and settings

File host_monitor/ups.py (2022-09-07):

#!/usr/bin/python3
# ---------------------------------------------------------------------------
#
# 	Raspberry Pi SuperUPS
#
# 	Copyright (C) 2020 Scott Baker
# 	Copyright (C) 2022 akuker
#
# 	[ Python class for reading/writting to the UPS controller ]
#
# ---------------------------------------------------------------------------

import smbus
import inspect
import logging
import enum


class SuperUPS:

    class States(enum.Enum):
        STATE_DISABLED = 0
        """Invalid state - not used by the controller."""
        STATE_WAIT_OFF = 1
        """During a commanded power cycle, delay in the 'off' state"""
        STATE_WAIT_ON = 2
        """Turn the power back on after a power cycle"""
        STATE_POWERUP = 3
        """Waiting for the super caps to charge after input power is restored"""
        STATE_RUNNING = 4
        """Normal running state of the super UPS"""
        STATE_POWER_LOSS_SHUTDOWN = 5
        """Wait for input power to be restored"""
        STATE_POWER_LOSS_SHUTDOWN_DELAY = 6
        """Input power is lost and the super caps have been discharged."""
        STATE_COMMANDED_POWER_CYCLE_DELAY = 7
        """Pi has commanded a power cycle. Remove power and delay"""

    I2C_CHARACTER_BUFFER = 1
    I2C_TEST_MODE_ENABLE = 2
    I2C_ADC_VOLTAGE_IN = 3
    I2C_ADC_VOLTAGE_OUT = 4
    I2C_ADC_SUPER_CAP_VOLTAGE = 5
    I2C_MOSFET_ENABLE = 6
    I2C_12V_ON_THRESH = 7
    I2C_12V_OFF_THRESH = 8
    I2C_COUNTDOWN = 9
    I2C_CURENT_STATE = 10
    I2C_CYCLE_DELAY = 11
    I2C_FAIL_SHUTDOWN_DELAY = 12
    I2C_RUN_COUNTER = 13
    I2C_UPS_POWERUP_THRESH = 14
    I2C_SHUTDOWN_THRESH = 15
    I2C_VOLTAGE_DIVIDER_R1_VALUE = 16
    I2C_VOLTAGE_DIVIDER_R2_VALUE = 17
    I2C_INTERFACE_VERSION = 18
    I2C_BUILD_VERSION = 19
    I2C_DEVICE_ID = 20
    I2C_POWER_BUTTON_STATE = 21
    I2C_AUX_BUTTON_STATE = 22
    I2C_DEBUG_LED_STATE = 23

    EXPECTED_INTERFACE_VERSION = 1

    def __init__(self, i2c_address=0x52):
        self.i2c_address = i2c_address
        self.logger = logging.getLogger('upsdaemon')
        try:
            self.bus = smbus.SMBus(1)
            if(self.interface_version != self.EXPECTED_INTERFACE_VERSION):
                print("WARNING: Unexpected interface version. SuperUPS may not work properly")
            self.cached_test_mode = False
            self.string_cache = ""
        except BaseException as err:
            self.logger.warning("Unable to connect to UPS controller: " + str(err))
            self.bus = None
            self.cached_test_mode = False

    def __del__(self):
        self.bus.close()

    #region debug text handling

    def _read_character(self):
        return self.bus.read_byte_data(self.i2c_address, self.I2C_CHARACTER_BUFFER)

    def read_string(self):
        logger = logging.getLogger('upsdaemon')
        while True:
            next_character = self._read_character()
            if(next_character == 0xFF):
                break
            else:
                if(chr(next_character) == '\n'):
                    return_string = self.string_cache
                    self.string_cache = ""
                    return return_string
                elif(chr(next_character) == '\r'):
                    pass
                elif(chr(next_character) == '\0'):
                    pass
                else:
                    logger.debug("Read char: {} (0x{})".format(chr(next_character), hex(next_character)))
                    self.string_cache = self.string_cache + chr(next_character)

        return None
    #endregion

    #region Voltages
    @property
    def input_voltage_raw(self):
        return self.bus.read_byte_data(self.i2c_address, self.I2C_ADC_VOLTAGE_IN)

    @input_voltage_raw.setter
    def input_voltage_raw(self, new_value):
        assert self.cached_test_mode, str(inspect.currentframe().f_code.co_name) + \
            " can only be modified in test mode"
        self.bus.write_byte_data(
            self.i2c_address, self.I2C_ADC_VOLTAGE_IN, new_value)

    @property
    def input_voltage(self):
        return self._convert_raw_to_voltage(self.input_voltage_raw)

    @input_voltage.setter
    def input_voltage(self, new_value):
        self.input_voltage_raw = self._convert_voltage_to_raw(new_value)

    @property
    def super_cap_voltage_raw(self):
        return self.bus.read_byte_data(self.i2c_address, self.I2C_ADC_SUPER_CAP_VOLTAGE)

    @super_cap_voltage_raw.setter
    def super_cap_voltage_raw(self, new_value):
        assert self.cached_test_mode, str(inspect.currentframe().f_code.co_name) + \
            " can only be modified in test mode"
        self.bus.write_byte_data(
            self.i2c_address, self.I2C_ADC_SUPER_CAP_VOLTAGE, new_value)

    @property
    def super_cap_voltage(self):
        return self._convert_raw_to_voltage(self.super_cap_voltage_raw)

    @super_cap_voltage.setter
    def super_cap_voltage(self, new_value):
        self.super_cap_voltage_raw = self._convert_voltage_to_raw(new_value)

    @property
    def output_voltage_raw(self):
        return self.bus.read_byte_data(self.i2c_address, self.I2C_ADC_VOLTAGE_OUT)

    @output_voltage_raw.setter
    def output_voltage_raw(self, new_value):
        assert self.cached_test_mode, str(inspect.currentframe().f_code.co_name) + \
            " can only be modified in test mode"
        self.bus.write_byte_data(
            self.i2c_address, self.I2C_ADC_VOLTAGE_OUT, new_value)

    @property
    def output_voltage(self):
        return self._convert_raw_to_voltage(self.output_voltage_raw)

    @output_voltage.setter
    def output_voltage(self, new_value):
        self.output_voltage_raw = self._convert_voltage_to_raw(new_value)

    def _convert_raw_to_voltage(self, raw_adc_value):
        r1 = self.r1_value
        r2 = self.r2_value
        # voltage into adc..... (raw_voltage/256) * 3.3
        # voltage divder formula.... Vout = (Vin * R2)/(R1+R2)
        # therefore Vin = (R1+R2) * (Vout/R2)
        voltage_out = (raw_adc_value/256) * 3.3
        voltage_in = (r1 + r2) * (voltage_out / r2)
        return_path = self._convert_voltage_to_raw(voltage_in)
        self.logger.debug("r1: {r1} r2: {r2} raw_in:{raw_input} adc_v:{adc_v} actual_v:{output} test_value:{test_value}".format(r1=r1, r2=r2, raw_input=raw_adc_value, adc_v=voltage_out, output=voltage_in, test_value=return_path))
        return voltage_in

    def _convert_voltage_to_raw(self, voltage):
        r1 = self.r1_value
        r2 = self.r2_value
        raw_voltage = (voltage * r2)/(r1+r2) * (256/3.3)
        self.logger.debug("r1: {r1} r2: {r2} voltage:{voltage} raw_value:{raw_value}".format(r1=r1, r2=r2, voltage=voltage, raw_value=raw_voltage))
        return int(raw_voltage)
    
    #endregion

    @property
    def test_mode(self):
        return self.bus.read_byte_data(self.i2c_address, self.I2C_TEST_MODE_ENABLE)

    @test_mode.setter
    def test_mode(self, new_value):
        self.cached_test_mode = bool(new_value)
        self.bus.write_byte_data(
            self.i2c_address, self.I2C_TEST_MODE_ENABLE, new_value)

    @property
    def power_on(self):
        return self.bus.read_byte_data(self.i2c_address, self.I2C_MOSFET_ENABLE)

    #region Power Thresholds

    @property
    def input_power_on_threshold_raw(self):
        return self.bus.read_byte_data(self.i2c_address, self.I2C_12V_ON_THRESH)

    @input_power_on_threshold_raw.setter
    def input_power_on_threshold_raw(self, new_value):
        self.bus.write_byte_data(
            self.i2c_address, self.I2C_12V_ON_THRESH, new_value)

    @property
    def input_power_on_threshold(self):
        return self._convert_raw_to_voltage(self.input_power_on_threshold_raw)

    @input_power_on_threshold.setter
    def input_power_on_threshold(self, new_value):
        self.input_power_on_threshold_raw = self._convert_voltage_to_raw(new_value)

    @property
    def input_power_off_threshold_raw(self):
        return self.bus.read_byte_data(self.i2c_address, self.I2C_12V_OFF_THRESH)

    @input_power_off_threshold_raw.setter
    def input_power_off_threshold_raw(self, new_value):
        self.bus.write_byte_data(
            self.i2c_address, self.I2C_12V_OFF_THRESH, new_value)

    @property
    def input_power_off_threshold(self):
        return self._convert_raw_to_voltage(self.input_power_off_threshold_raw)

    @input_power_off_threshold.setter
    def input_power_off_threshold(self, new_value):
        self.input_power_off_threshold_raw = self._convert_voltage_to_raw(new_value)

    @property
    def ups_powerup_voltage_threshold_raw(self):
        return self.bus.read_byte_data(self.i2c_address, self.I2C_UPS_POWERUP_THRESH)

    @ups_powerup_voltage_threshold_raw.setter
    def ups_powerup_voltage_threshold_raw(self, new_value):
        self.bus.write_byte_data(
            self.i2c_address, self.I2C_UPS_POWERUP_THRESH, new_value)

    @property
    def ups_powerup_voltage_threshold(self):
        return self._convert_raw_to_voltage(self.ups_powerup_voltage_threshold_raw)

    @ups_powerup_voltage_threshold.setter
    def ups_powerup_voltage_threshold(self, new_value):
        self.ups_powerup_voltage_threshold_raw = self._convert_voltage_to_raw(new_value)

    @property
    def shutdown_voltage_threshold_raw(self):
        return self.bus.read_byte_data(self.i2c_address, self.I2C_SHUTDOWN_THRESH)

    @shutdown_voltage_threshold_raw.setter
    def shutdown_voltage_threshold_raw(self, new_value):
        self.bus.write_byte_data(
            self.i2c_address, self.I2C_SHUTDOWN_THRESH, new_value)

    @property
    def shutdown_voltage_threshold(self):
        return self._convert_raw_to_voltage(self.shutdown_voltage_threshold_raw)

    @shutdown_voltage_threshold.setter
    def shutdown_voltage_threshold(self, new_value):
        self.shutdown_voltage_threshold_raw = self._convert_voltage_to_raw(new_value)
    #endregion 

    @property
    def current_state(self):
        return self.bus.read_byte_data(self.i2c_address, self.I2C_CURENT_STATE)

    @current_state.setter
    def current_state(self, new_value):
        assert self.cached_test_mode, str(inspect.currentframe().f_code.co_name) + \
            " can only be modified in test mode"
        self.bus.write_byte_data(
            self.i2c_address, self.I2C_CURENT_STATE, new_value)

    @property
    def current_state_string(self):
        return str(SuperUPS.States(self.current_state))

    @property
    def r1_value(self):
        return self.bus.read_byte_data(self.i2c_address, self.I2C_VOLTAGE_DIVIDER_R1_VALUE)

    @r1_value.setter
    def r1_value(self, new_value):
        assert self.cached_test_mode, str(inspect.currentframe().f_code.co_name) + \
            " can only be modified in test mode"
        self.cached_r1 = new_value
        self.bus.write_byte_data(
            self.i2c_address, self.I2C_VOLTAGE_DIVIDER_R1_VALUE, new_value)

    @property
    def r2_value(self):
        return self.bus.read_byte_data(self.i2c_address, self.I2C_VOLTAGE_DIVIDER_R2_VALUE)

    @r2_value.setter
    def r2_value(self, new_value):
        assert self.cached_test_mode, str(inspect.currentframe().f_code.co_name) + \
            " can only be modified in test mode"
        self.cached_r2 = new_value
        self.bus.write_byte_data(self.i2c_address, self.I2C_VOLTAGE_DIVIDER_R2_VALUE, new_value)

    @property
    def command_shutdown_counter(self):
        return self.bus.read_byte_data(self.i2c_address, self.I2C_COUNTDOWN)

    @command_shutdown_counter.setter
    def command_shutdown_counter(self, new_value):
        self.bus.write_byte_data(self.i2c_address, self.I2C_COUNTDOWN, new_value)

    @property
    def interface_version(self):
        return self.bus.read_byte_data(self.i2c_address, self.I2C_INTERFACE_VERSION)

    @property
    def build_id(self):
        return self.bus.read_byte_data(self.i2c_address, self.I2C_BUILD_VERSION)

    @property
    def device_id(self):
        return self.bus.read_byte_data(self.i2c_address, self.I2C_DEVICE_ID)

    @property
    def power_button_state(self):
        return self.bus.read_byte_data(self.i2c_address, self.I2C_POWER_BUTTON_STATE)

    @power_button_state.setter
    def power_button_state(self, new_value):
        assert self.cached_test_mode, str(inspect.currentframe().f_code.co_name) + \
            " can only be modified in test mode"
        self.bus.write_byte_data(
            self.i2c_address, self.I2C_POWER_BUTTON_STATE, new_value)

    @property
    def aux_button_state(self):
        return self.bus.read_byte_data(self.i2c_address, self.I2C_AUX_BUTTON_STATE)

    @aux_button_state.setter
    def aux_button_state(self, new_value):
        assert self.cached_test_mode, str(inspect.currentframe().f_code.co_name) + \
            " can only be modified in test mode"
        self.bus.write_byte_data(
            self.i2c_address, self.I2C_AUX_BUTTON_STATE, new_value)

    @property
    def debug_led_state(self):
        return self.bus.read_byte_data(self.i2c_address, self.I2C_DEBUG_LED_STATE)

    @debug_led_state.setter
    def debug_led_state(self, new_value):
        self.bus.write_byte_data(
            self.i2c_address, self.I2C_DEBUG_LED_STATE, new_value)

    def dump_status(self):
        print("({num:2}) I2C_TEST_MODE_ENABLE = {value}".format(num=self.I2C_TEST_MODE_ENABLE, value=self.test_mode))
        print("({num:2}) I2C_ADC_VOLTAGE_IN = {value}".format(num=self.I2C_ADC_VOLTAGE_IN, value=self.input_voltage))
        print("({num:2}) I2C_ADC_VOLTAGE_OUT = {value}".format(num=self.I2C_ADC_VOLTAGE_OUT, value=self.output_voltage))
        print("({num:2}) I2C_ADC_SUPER_CAP_VOLTAGE = {value}".format(num=self.I2C_ADC_SUPER_CAP_VOLTAGE, value=self.super_cap_voltage))
        print("({num:2}) I2C_MOSFET_ENABLE = {value}".format(num=self.I2C_MOSFET_ENABLE, value=self.power_on))
        print("({num:2}) I2C_12V_ON_THRESH = {value}".format(num=self.I2C_12V_ON_THRESH, value=self.input_power_on_threshold))
        print("({num:2}) I2C_12V_OFF_THRESH = {value}".format(num=self.I2C_12V_OFF_THRESH, value=self.input_power_off_threshold))
        print("({num:2}) I2C_COUNTDOWN = {value}".format(num=self.I2C_COUNTDOWN, value=self.command_shutdown_counter))
        print("({num:2}) I2C_CURENT_STATE = {value}".format(num=self.I2C_CURENT_STATE, value=self.current_state))
        print("({num:2}) I2C_CYCLE_DELAY = {value}".format(num=self.I2C_CYCLE_DELAY, value=self.bus.read_byte_data(self.i2c_address, self.I2C_CYCLE_DELAY)))
        print("({num:2}) I2C_FAIL_SHUTDOWN_DELAY = {value}".format(num=self.I2C_FAIL_SHUTDOWN_DELAY, value=self.bus.read_byte_data(self.i2c_address, self.I2C_FAIL_SHUTDOWN_DELAY)))
        print("({num:2}) I2C_RUN_COUNTER = {value}".format(num=self.I2C_RUN_COUNTER, value=self.bus.read_byte_data(self.i2c_address, self.I2C_RUN_COUNTER)))
        print("({num:2}) I2C_UPS_POWERUP_THRESH = {value}".format(num=self.I2C_UPS_POWERUP_THRESH, value=self.bus.read_byte_data(self.i2c_address, self.I2C_FAIL_SHUTDOWN_DELAY)))
        print("({num:2}) I2C_SHUTDOWN_THRESH = {value}".format(num=self.I2C_SHUTDOWN_THRESH, value=self.shutdown_voltage_threshold))
        print("({num:2}) I2C_VOLTAGE_DIVIDER_R1_VALUE = {value}".format(num=self.I2C_VOLTAGE_DIVIDER_R1_VALUE, value=self.r1_value))
        print("({num:2}) I2C_VOLTAGE_DIVIDER_R2_VALUE = {value}".format(num=self.I2C_VOLTAGE_DIVIDER_R2_VALUE, value=self.r2_value))
        print("({num}) I2C_INTERFACE_VERSION = {value}".format(num=self.I2C_INTERFACE_VERSION , value=self.interface_version))
        print("({num}) I2C_BUILD_VERSION = {value}".format(num=self.I2C_BUILD_VERSION , value=self.build_id))
        #print("{num} I2C_DEVICE_ID = {value}".format(num=self.I2C_DEVICE_ID , value=self.)
        print("({num:2}) I2C_POWER_BUTTON_STATE = {value}".format(num=self.I2C_POWER_BUTTON_STATE, value=self.power_button_state))
        print("({num:2}) I2C_AUX_BUTTON_STATE = {value}".format(num=self.I2C_AUX_BUTTON_STATE, value=self.aux_button_state))
        print("({num:2}) I2C_DEBUG_LED_STATE = {value}".format(num=self.I2C_DEBUG_LED_STATE, value=self.debug_led_state))

    def is_valid(self):
        if(self.bus is None):
            print("Warning: self.bus is none")
            return False
        #TODO: Figure out the interface version thing
        #if(self.interface_version != self.EXPECTED_INTERFACE_VERSION):
        #    print("Interface version is not as expected")
        #    return False
        return True

    def is_invalid(self):
        return not self.is_valid()


if __name__ == "__main__":
    my_ups = SuperUPS()
    print("Device ID " + str(my_ups.device_id))
    my_ups.dump_status()
    my_ups.test_mode = True
    print("Test Mode: " + str(my_ups.test_mode))
    my_ups.input_voltage = 5
    print("Input Voltage: " + str(my_ups.input_voltage))
    my_ups.test_mode = False
    print("Test Mode: " + str(my_ups.test_mode))
    print("the following statement should crash")
    my_ups.input_voltage = 5

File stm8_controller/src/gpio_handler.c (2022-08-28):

//---------------------------------------------------------------------------
//
//	Raspberry Pi SuperUPS
//
//	Copyright (C) 2020 Scott Baker
//	Copyright (C) 2022 akuker
//
//	[ GPIO Handler ]
//
//  Reads the 2 pushbutton inputs and writes the state of these inputs to
//  I2C registers
//
//---------------------------------------------------------------------------

#include "gpio_handler.h"
#include "i2c_register_data.h"
#include <stdint.h>
#include <stm8s.h>

#define NUM_DEBOUNCE_SAMPLES 4

uint8_t shutdown_button_states[NUM_DEBOUNCE_SAMPLES];
uint8_t auxiliary_button_states[NUM_DEBOUNCE_SAMPLES];

static uint8_t current_idx = 0;

static bool debounce_samples_match(uint8_t *samples)
{
    bool match = TRUE;
    for (int i = 1; i < NUM_DEBOUNCE_SAMPLES; i++)
    {
        if (samples[i - 1] != samples[i])
        {
            match = FALSE;
        }
    }
    return match;
}

void gpios_init()
{

    // There is a pull-up resistor on this input, so a "1" means
    // that the button is NOT pressed
    i2c_register_values[I2C_POWER_BUTTON_STATE] = 1;
    i2c_register_values[I2C_AUX_BUTTON_STATE] = 1;
    GPIO_Init(GPIOC, GPIO_PIN_5, GPIO_MODE_IN_FL_NO_IT);
    GPIO_Init(GPIOC, GPIO_PIN_6, GPIO_MODE_IN_FL_NO_IT);
    GPIO_Init(GPIOC, GPIO_PIN_7, GPIO_MODE_OUT_OD_LOW_SLOW);
}
void gpios_step()
{
    if (i2c_register_values[I2C_DEBUG_LED_STATE])
    {
        GPIO_WriteLow(GPIOC, GPIO_PIN_7);
    }
    else
    {
        GPIO_WriteHigh(GPIOC, GPIO_PIN_7);
    }

    shutdown_button_states[current_idx] = GPIO_ReadInputPin(GPIOC, GPIO_PIN_5);
    auxiliary_button_states[current_idx] = GPIO_ReadInputPin(GPIOC, GPIO_PIN_6);

    // Only update the global values if we're NOT in test mode
    if (i2c_register_values[I2C_TEST_MODE_ENABLE] == 0)
    {
        if (debounce_samples_match(shutdown_button_states))
        {
            i2c_register_values[I2C_POWER_BUTTON_STATE] = shutdown_button_states[0];
        }
        if (debounce_samples_match(auxiliary_button_states))
        {
            i2c_register_values[I2C_AUX_BUTTON_STATE] = auxiliary_button_states[0];
        }
    }

    current_idx = (current_idx + 1) % NUM_DEBOUNCE_SAMPLES;
}

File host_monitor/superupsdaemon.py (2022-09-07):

#!/usr/bin/python3
# ---------------------------------------------------------------------------
#
# 	Raspberry Pi SuperUPS
#
# 	Copyright (C) 2020 Scott Baker
# 	Copyright (C) 2022 akuker
#
# 	[ Controller interface for the SuperUPS ]
#
# ---------------------------------------------------------------------------

import argparse
import daemon
import os
import signal
import sys
import time
import traceback
import logging

from ups import SuperUPS


SHUTDOWN_COMMAND = "/sbin/shutdown -h now",

# Global flags to terminate the daemon
glo_Usr1Received = False
glo_HupReceived = False

global this_ups

# create logger
global logger


def signal_hup(sig, stack):
    global glo_HupReceived
    glo_HupReceived = True


def signal_usr1(sig, stac):
    global glo_Usr1Received
    glo_Usr1Received = True


def monitor():
    global glo_Usr1Received, glo_HupReceived
    global this_ups, SHUTDOWN_COMMAND, logger

    debug_led_state = False
    # Counter to only check the voltage every second.
    count = 0

    signal.signal(signal.SIGHUP, signal_hup)
    signal.signal(signal.SIGUSR1, signal_usr1)
    logger.info("Starting monitor...")
    while True:
        try:
            count = count + 1
            if count > 999:
                count = 0

            v_in = this_ups.input_voltage
            v_threshold = this_ups.input_power_off_threshold
            logger.debug("VIN: %0.2f V_Threshold: %0.2f" % (v_in, v_threshold))
            logger.debug(this_ups.current_state_string)

            if(v_in < v_threshold):
                if (count % 10) == 0:
                    logger.warning("Power removed! VIN %0.2f is below threshold %0.2f !!!! Shutting down!!!" % (v_in, v_threshold))

            if(SuperUPS.States(this_ups.current_state) != SuperUPS.States.STATE_RUNNING):
                logger.warning("State has transitioned to " + this_ups.current_state_string)
                logger.warning("Commanding a Shutdown")
                os.system(SHUTDOWN_COMMAND)

            if glo_Usr1Received:
                glo_Usr1Received = False
                this_ups.dump_status()

            if glo_HupReceived:
                glo_HupReceived = False
                logger.warning("HUP Received!")
                logger.warning("exiting")
                return
                # logger.warning("Executing shutdown command %s" % SHUTDOWN_COMMAND)
                # os.system(SHUTDOWN_COMMAND)

            if (count % 10) == 0:
                # Toggle LED to show that this service is running
                logger.info("[Input Voltage: %0.2f] Setting LED to %d" % (v_in, debug_led_state))
                this_ups.debug_led_state = int(debug_led_state)
                debug_led_state = not debug_led_state

            # if debug logging is enabled, we'll pull the character buffer
            # from the UPS controller
            if logger.isEnabledFor(logging.DEBUG):
                while True:
                    debug_str = this_ups.read_string()
                    if(debug_str is None):
                        break
                    logger.debug("[ Controller message ] {}".format(debug_str))

        except:
            traceback.print_exc()

        time.sleep(0.1)


def sleep_forever():
    global logger
    logger.info("There doesn't seem to be a functional UPS attached. Going to sleep forever....")
    while not glo_HupReceived:
        logger.debug("Sleeping....")
        time.sleep(1)


if __name__ == "__main__":
    global my_ups
    global logger
    
    logger = logging.getLogger('upsdaemon')
    logger.setLevel(logging.INFO)

    # create console handler and set level to debug
    ch = logging.StreamHandler()

    # create formatter
    formatter = logging.Formatter('%(asctime)s - %(name)s - %(levelname)s - %(message)s')

    # add formatter to ch
    ch.setFormatter(formatter)
    # ch.setLevel(logging.DEBUG)

    # add ch to logger
    logger.addHandler(ch)

    try:
        this_ups = SuperUPS()
    except BaseException as err:
        logger.warning("An exception occurred while trying to create the UPS connection" + str(err))
        this_ups = None

    if this_ups is None or this_ups.is_invalid():
        sleep_forever()

    # context = daemon.DaemonContext(stdout=sys.stdout, stderr=sys.stderr)
    # with context:
    monitor()

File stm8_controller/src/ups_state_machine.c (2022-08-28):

//---------------------------------------------------------------------------
//
//	Raspberry Pi SuperUPS
//
//	Copyright (C) 2020 Scott Baker
//	Copyright (C) 2022 akuker
//
//	[ SuperUPS master state machine ]
//
//---------------------------------------------------------------------------

#include "ups_constants.h"
#include "i2c_register_data.h"
#include <stdio.h>

static uint8_t *current_state = &i2c_register_values[I2C_CURENT_STATE];
static uint8_t *input_voltage = &i2c_register_values[I2C_ADC_VOLTAGE_IN];
static uint8_t *ups_voltage = &i2c_register_values[I2C_ADC_SUPER_CAP_VOLTAGE];
static uint8_t *ups_power_valid_threshold = &i2c_register_values[I2C_UPS_POWERUP_THRESH];
static uint8_t *on_voltage_threshold = &i2c_register_values[I2C_12V_ON_THRESH];
static uint8_t *off_voltage_threshold = &i2c_register_values[I2C_12V_OFF_THRESH];
static uint8_t *mosfet_enable = &i2c_register_values[I2C_MOSFET_ENABLE];

static uint8_t *power_loss_delay_counter = &i2c_register_values[I2C_FAIL_SHUTDOWN_DELAY];
static uint8_t *commanded_power_cycle_counter = &i2c_register_values[I2C_CYCLE_DELAY];

static uint8_t *commanded_power_cycle_countdown = &i2c_register_values[I2C_COUNTDOWN];
static uint8_t *run_counter = &i2c_register_values[I2C_RUN_COUNTER];

void ups_init()
{
    *current_state = STATE_POWERUP;
}

void ups_step()
{

    switch (*current_state)
    {
    case STATE_DISABLED:
        // state machine is disabled -- do nothing
        break;

    case STATE_WAIT_OFF:
        if (*input_voltage <= *off_voltage_threshold)
        {
            *current_state = STATE_WAIT_ON;
        }
        break;

    case STATE_WAIT_ON:
        if (*input_voltage >= *on_voltage_threshold)
        {
            *current_state = STATE_POWERUP;
        }
        break;

    case STATE_POWER_LOSS_SHUTDOWN:
    case STATE_POWERUP:
        // Wait for the input voltage to be on and the super capacitors to be charged
        if ((*input_voltage >= *on_voltage_threshold) && (*ups_voltage >= *ups_power_valid_threshold))
        {
            *commanded_power_cycle_countdown = 0;
            *mosfet_enable = 1;
            *current_state = STATE_RUNNING;
        }
        break;

    case STATE_RUNNING:
        // If the input voltage is off/low and the super capacitors voltage
        // is too low, start a countdown to shut off the power output
        if ((*input_voltage <= *off_voltage_threshold) && (*ups_voltage <= *ups_power_valid_threshold))
        {
            // function gets called about every 100ms. Delay 5s
            *power_loss_delay_counter = 50;
            *current_state = STATE_POWER_LOSS_SHUTDOWN_DELAY;
        }
        // Check to see if the host has commanded a power cycle
        if (*commanded_power_cycle_countdown > 0)
        {
            // the run_counter should be updating at 1ms
            // the commanded power cycle is specified in 10ms increments
            if ((*run_counter % 10) == 0)
            {
                *commanded_power_cycle_countdown--;
            }
            if (*commanded_power_cycle_countdown == 0)
            {
                // Give the Pi 5 seconds to shut down
                *commanded_power_cycle_counter = 50;
                *current_state = STATE_COMMANDED_POWER_CYCLE_DELAY;
            }
        }
        break;

    case STATE_POWER_LOSS_SHUTDOWN_DELAY:
        // delay so the pi can safely power cycle
        if (*power_loss_delay_counter > 0)
        {
            *power_loss_delay_counter = *power_loss_delay_counter - 1;
        }
        else
        {
            // shutdown due to power failure; 
            *current_state = STATE_POWER_LOSS_SHUTDOWN;
            *mosfet_enable = 0;
        }
        break;

    case STATE_COMMANDED_POWER_CYCLE_DELAY:
        // shutdown due to power-off request; delay so the pi can safely power cycle
        if (*commanded_power_cycle_counter > 0)
        {
            *commanded_power_cycle_counter = *commanded_power_cycle_countdown - 1;
        }
        if (*commanded_power_cycle_counter == 0)
        {
            *current_state = STATE_WAIT_OFF;
            *mosfet_enable = 0;
        }
        break;
    }

    *run_counter++;
}

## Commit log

2022-05-19 Reorganized directories
    [ups-scrunched.GBL, ups-scrunched.GBO, ups-scrunched.GBS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]
2022-05-19 Move akuker supercap board from github.com/akuker/hw_projects
    [SLO0530H_Model.FCStd, buck_conerter.kicad_sch, jlcpcb_bom.csv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]
2022-05-19 Update and rename i2c_registers.md to microcontroller_design.md
2022-05-19 pictures of the board
2022-05-24 Demo project to blink the led
2022-05-31 working uart with SPL
2022-05-31 blinky and uart working
2022-05-31 i2cdetect runs VERY slow
2022-05-31 i2c detection works!
2022-05-31 i2cset and i2cget working
2022-05-31 read real adc data
2022-05-31 enabled printf
2022-06-01 demo I2c program
2022-06-02 updates... pulled in buck conv
    [12v_buck_converter.kicad_sch, ras_pi_supercap_ups.kicad_pcb, ras_pi_supercap_ups.kicad_sch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]
2022-06-02 Updates - candidate board layout
    [12v_buck_converter.kicad_sch, ras_pi_supercap_ups.kicad_pcb, ras_pi_supercap_ups.kicad_sch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]
2022-06-18 Integrated with v9.5 board. Enabled state machine
2022-06-20 Added timer-based delay functions
2022-06-20 github wants carriage returns at the end of the file
2022-06-20 adjust main loop timer and adjust debug rs-232 output
2022-06-24 Add gpio handler and device id
2022-06-24 Integrated shutdown/aux button reading
2022-06-26 initial commit v1p0
    [12v_buck_converter.kicad_sch, SLO0530H_Model.FCStd, buck_conerter.kicad_sch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]
2022-06-29 Added note about R26
    [12v_buck_converter.kicad_sch]
2022-07-02 Last version before removing mosfet
    [12v_buck_converter.kicad_sch, ras_pi_supercap_ups.kicad_pcb, ras_pi_supercap_ups.kicad_sch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]
2022-07-02 Removed Mosfet - release candidate 1.0
    [12v_buck_converter.kicad_sch, ras_pi_supercap_ups.kicad_pcb, ras_pi_supercap_ups.kicad_sch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]
2022-07-02 Change power control resistor to jumper
    [12v_buck_converter.kicad_sch, ras_pi_supercap_ups.kicad_sch]
2022-07-05 As-Ordered version
    [12v_buck_converter.kicad_sch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]
2022-07-15 Add option to send STDOUT over the i2c bus
2022-07-19 Added register to control debug LED
2022-07-19 moved daemon to separate file. Added raw/voltage conversions
2022-07-20 Pogo pin holder
    [ras_pi_supercap_ups-B_Cu.gbl, ras_pi_supercap_ups-B_Mask.gbs, ras_pi_supercap_ups-B_Paste.gbp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]
2022-08-07 Remove debug output. Print state transitions and build date only
2022-08-07 archive test for the ring buffer. Replace main.c with this file
    [test_ring_buff.c]
2022-08-07 fix delay after power loss to hold up Pi for max 5 seconds
    [main.c, ups_state_machine.c]
2022-08-08 change i2c clock to 1Mhz for better compatibility
